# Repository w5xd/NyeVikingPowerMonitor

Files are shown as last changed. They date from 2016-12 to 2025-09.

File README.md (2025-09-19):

# Nye Viking RF Power Monitor
Brain transplant for Nye Viking Power Monitor RFM-003

My old RFM-003 quit working. I had purchased it new in 1988 and it has been my go-to device
ever since. It was produced by Nye Viking 
in Bellevue, Washington  through the 1980's and 1990's. Its original 
design is an analog computer that converts the two voltages (forward and reflected) from a directional coupler to present an SWR reading and 
an RF Power reading on analog meters. 

After switching out the obvious parts, I gave up trying to fix mine and
instead started prototyping with an Arduino single-board computer and its mating Proto Shield circuit board.
This git repo documents the hardware and software needed to replace the OEM analog computer with what I finally came up with: an
Arduino-based custom printed circuit board (PCB).  

Old Nye Viking power meters also become available from time to time "for parts only."
This project presents a four layer PCB design that has the same functions as the OEM PCB, supports the
same switches and connectors on the OEM device's front and back panels, and can be retrofitted into an OEM RFM-003 console
to restore all of its original functionality.

Don't know about the Nye Viking Power Monitor? Here is a demonstration videoed by N8RWS:<br/> http://www.youtube.com/watch?v=muCM9BKhpKA

When I did the retrofit of my own two Nye Viking consoles, I took the liberty of making three
exernally visible changes: I substituted 
RGB diodes on the front panel, drilled a small back panel hole for a USB port, and placed a small
momentary contact SPST switch in what was the back panel ALO sense adjustment hole. If you forego those three
substitutions, you can make it difficult to distinguish the OEM console from the retrofit&mdash;even in operation.  (Spoiler:
feed the retrofit less than 20W and it changes the front panel LED color and brightness while simultaneously
displaying the power meter readout multiplied by 10, which the OEM won't do.) 

# History
The original instrument has a single circuit board. Here is a photo with its cover removed.
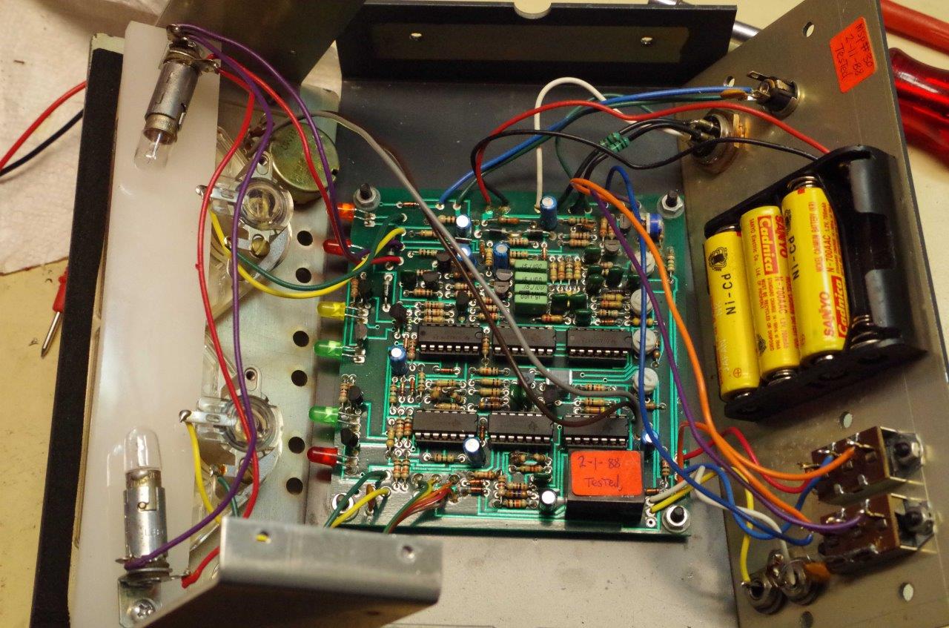
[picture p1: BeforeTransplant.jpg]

<p> This github repo documents 
a replacement project done in 2023 that is based on a custom printed circuit board documented
in the PCB folder. If you want the full history, the git tag 
<a href='https://github.com/w5xd/NyeVikingPowerMonitor/tree/Final-Haywire-Prototype'>Final-Haywire-Prototype</a> 
documents the first steps in this project back to 2016, and before the design of the custom
PCB. </p>

September, 2025

The latest revision updates the sketch, replaces
the console 3D printable work-alike, and updates the PCB design. 

<h2>Construction</h2>
The custom PCB is 2 inches by 4 inches. Its circuit diagram is <a href='PCB/schematics.pdf'>
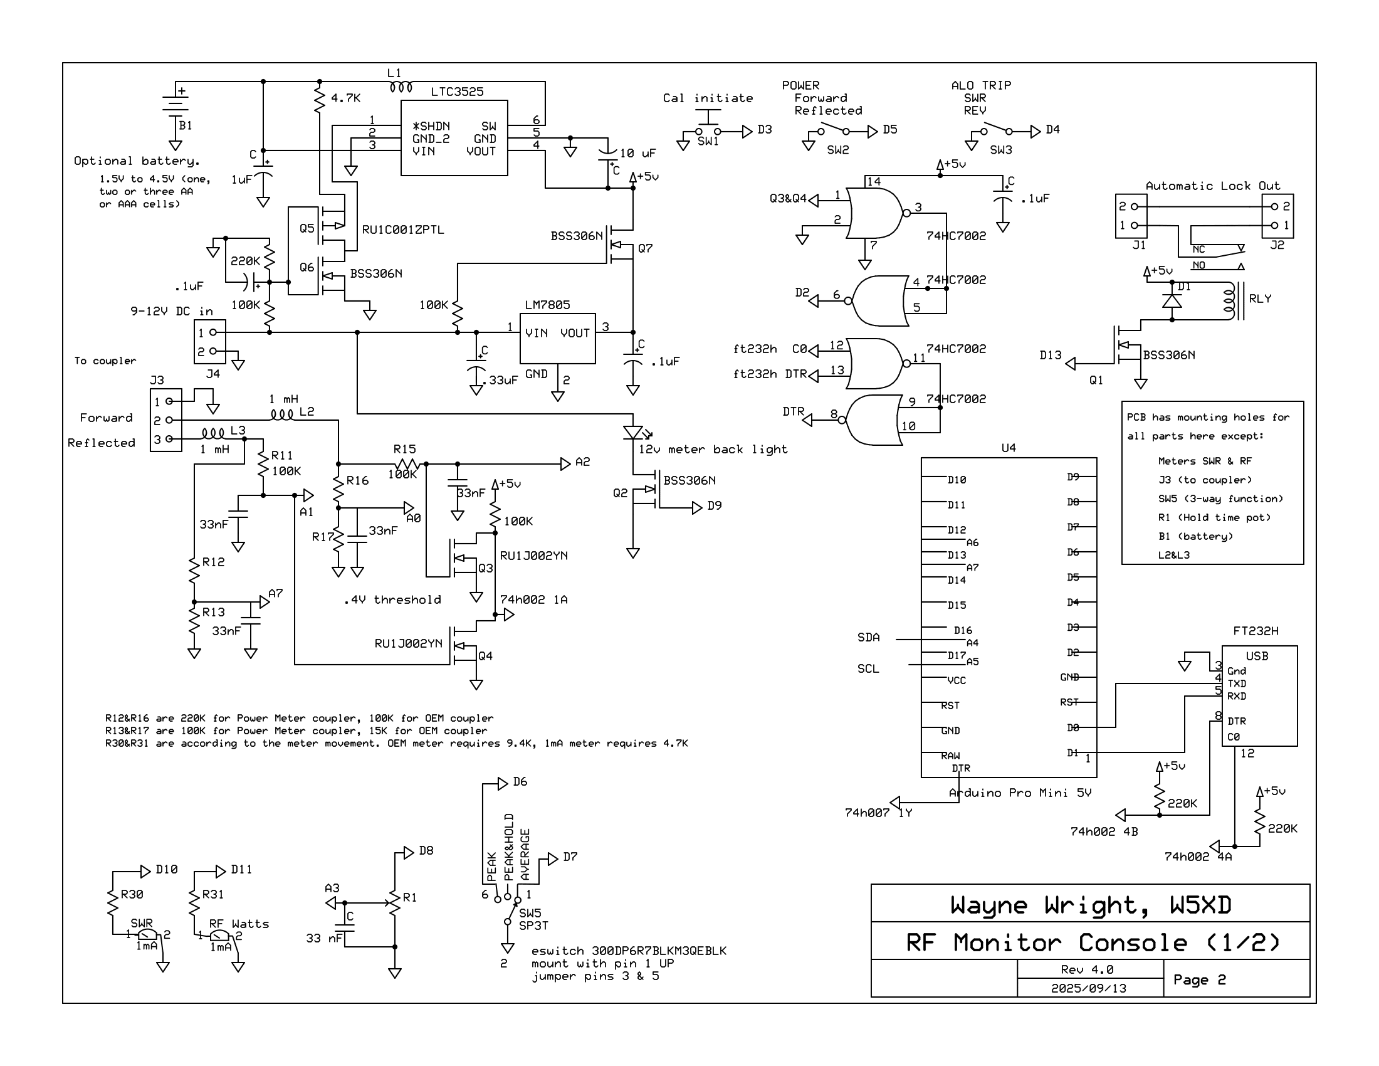
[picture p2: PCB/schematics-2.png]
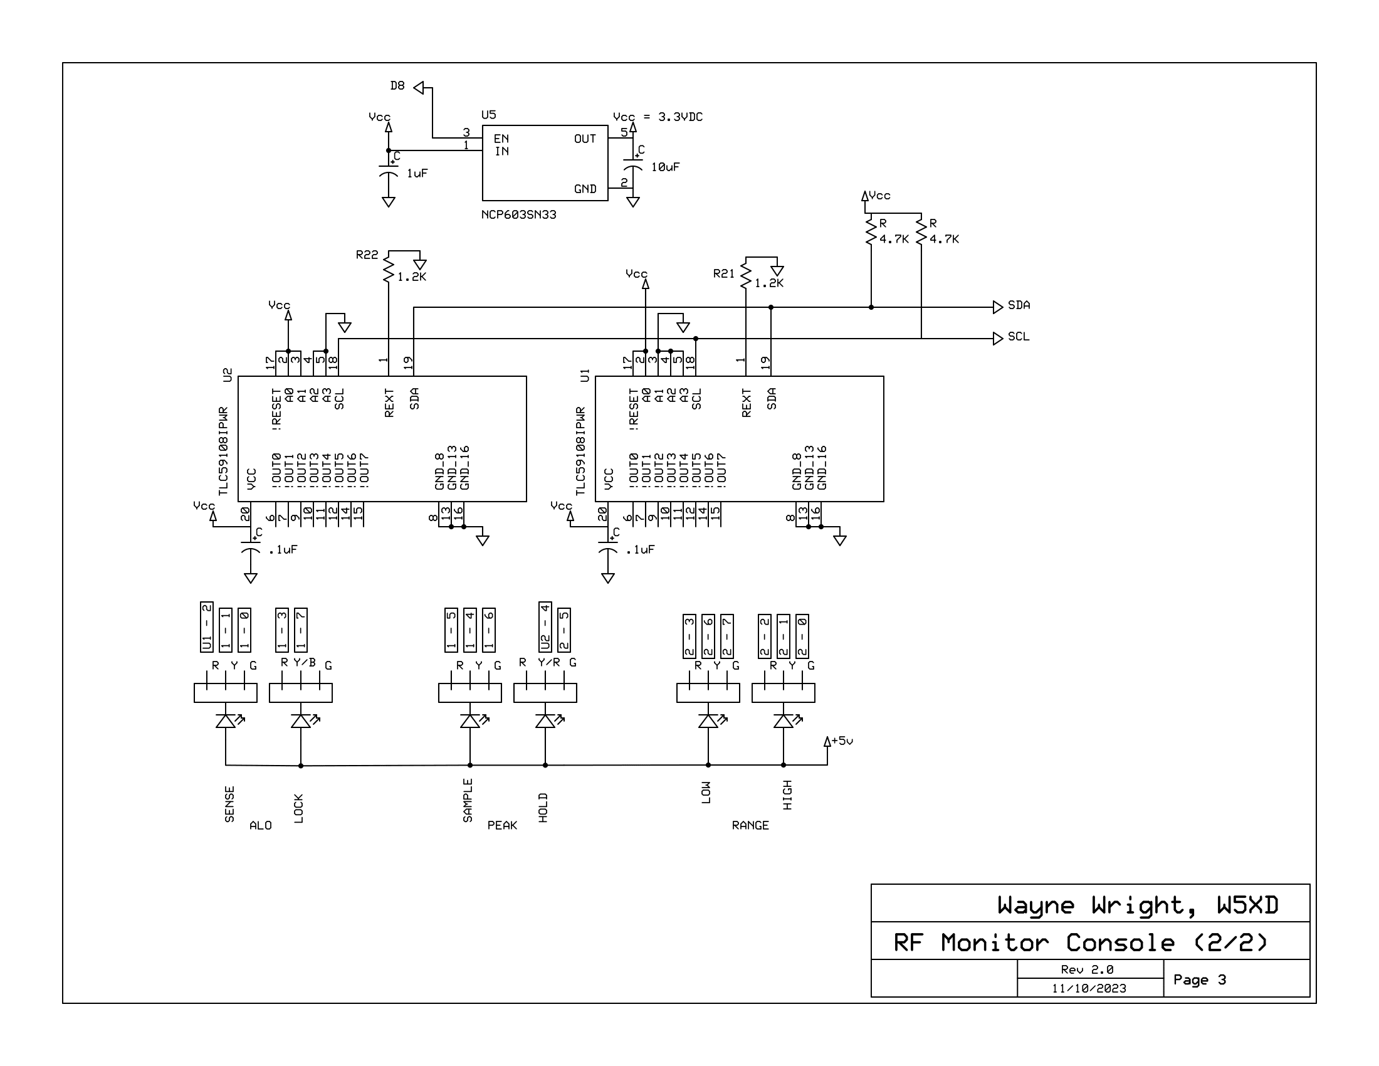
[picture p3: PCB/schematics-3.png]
page3
</a>The
PCB's construction sources are 
published here in the format supported by expresspcb.com, along with gerber files that
commercial PCB manufacturers can use to reproduce them. Parts lists
for duplicating this retrofit are linked below. Two additional projects are documented:
<ul>
<li>A work-alike console can be bult using the same retrofit PCB and it fits in the 3D printed enclosure documented below.
<li>The directional coupler documented below supports the range 1.8MHz to 29MHz and power between 5W to 3000W. 
The retrofit PCB will work with it, whether in an OEM console that maybe you acquired without its coupler, or with
the work-alike console. (The only combination that doesn't work is the 
unmodifed OEM console will <i>not</i> work with this coupler, even though the
connectors are compatible.)
</ul>

# OEM console disassembly
<p>The original box splits along its clam shell by first removing the top two screws from the right hand side,
the top two screws from the left hand side to remove the top. Then the outer-most four screws from the back panel.
To fold the front panel away, remove the bottom two screws <i>on the two side panels only</i>.
 Do not remove any
front panel screws nor the bottom panel screws.</p>
<p>I removed the original board by snipping each wire at its end at the original circuit board. 
Some of the resulting wires
will reach to their assigned position on the new PCB, but some will not. The custom PCB
fits onto a 3D printed bracket that has holes to match the original four #6 screws that held the OEM
PCB in place, and that has six by 5mm LED holes to match the front panel LEDs. The bracket holds the
custom PCB at an angle.</p>
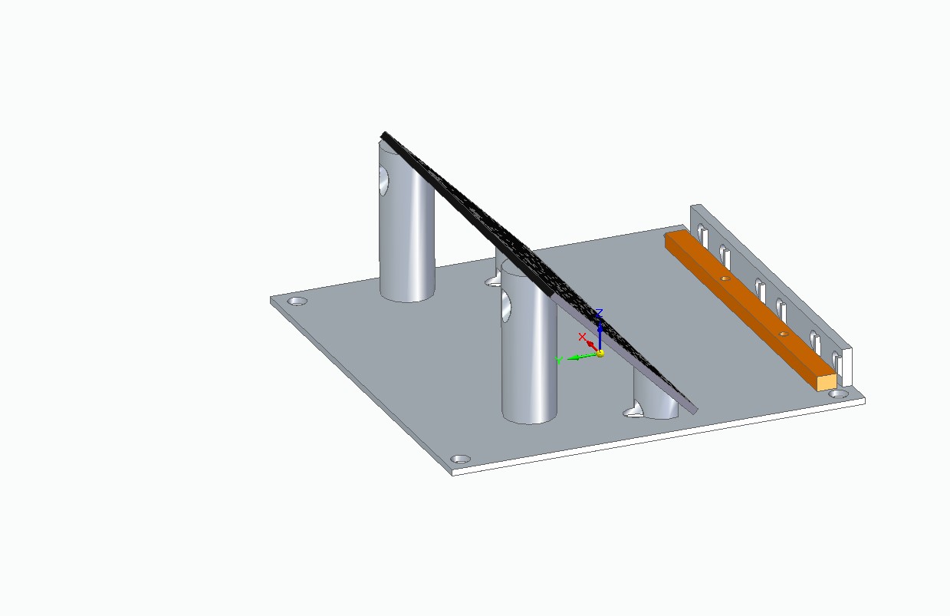
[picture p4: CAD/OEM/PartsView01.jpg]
OEM view

<p>A prospective builder will want to know that, while the 12VDC connector at the back
of the RFM-003 matches the voltage (about 12V), polarity (positive on the inner pin, 2.5mm) and
outer diameter, (5.5mm) that is standard on AVR-based Arduinos, the diameters of the inner pins do NOT match. The Arduino power plugs have
a 2.1mm inner pin. </p>

<a href='PCB/ConsolePcbMap.pdf'>Map of the console PCB</a>

<h2>Added low-low power feature</h2>
<p>While the code (nearly) duplicates the original behavior of the analog board, there is
 one additional low power readout feature. When it detects power levels below 1/10 of full scale in the LOW RANGE, it 
 multiplies the value on the meter by 10 (so 5 watts goes to 50 on the meter scale) and 
it changes the color of, and lowers the brightness of, the LOW LED.
</p>
<h2>SWR and RF Power</h2>
The DC voltages from the OEM coupler are input on a 4 pin jack. The pins are ground, foward signal, 
reflected signal, and battery charge. The retrofit PCB does not have a battery recharge circuit.
Therefore there is no connection on the battery charge
voltage on that fourth pin, but is built with a 4 pin connector that mates compatibly with OEM part.
 The forward and reflected signal voltages are processed into
 SWR and RF power readings that are presented on analog meters. The overall signal processing is
equivalent in this retrofit to the OEM design. 
The sketch supports a compile time option to construct lookup tables for analog meter movements, either 
<ol type='a'>
<li>the OEM meters with their original scales. This is for a retrofit.
<li>1 mA movement meters with the mA scale replaced using the printout from the MeterFaces application here.
Without OEM meters, constructing a workalike console requires modifying commercially available meter faces
as described below.
</ol>

<h2>Switches and Potentiometer</h2>
This retrofit takes all the same user inputs as the original:
<ul>
<li>Front panel potentiometer for Hold Time
<li>Front panel three-position switch for metering mode: Peak, Peak & Hold, Average
<li>Back panel ALO selection between SWR and Reverse Power
<li>Back panel Power selection between Forward and Reflected to drive the front panel Power meter
<li>Back panel ALO RCA jacks that break continuity on detecting a lock out condition.
</ul>
<p>The retrofit adds a momentary action pushbutton switch to the back panel that is not in the OEM design. Pressing 
the button places the meter 
in calibrate mode so that
you can adjust, within a restricted range, the meter's power sensitivity. This feature is in lieu of the
calibration pots on the OEM PCB. A commerically available
push button SPST switch fits in the OEM case in the original hole labeled ALO Adjust. That is, you
don't need to drill any new holes for a retrofit
</p>

<h2>Forward and Reflected signals</h2>
<p>
In this retrofit design, the Forward and Reflected readings from the coupler are treated identically 
to each other in the circuits leading up to
the analog to digital conversion. Each signal input is fed undivided into an ADC input on the Arduino through a 
100K resistor.
This signal path is used for best resolution at low RF power up until the digitized voltage exceeds
the 5V maximum supported by the Arduino ADC inputs. The 100K resistor
limits current under high power signals which can range up to about 15V for this coupler, or 26V for the
OEM 3000W coupler. The forward power signal is also voltage divided into a second ADC input channel, 
with the divider set to be enough to bring
the highest measureable power (3000W) down below the 5V maximum. The program in the sketch
tries the undivided voltage first, notes if it is maxed out and then tries again with the divided input. This
allocation of two ADC pins for each power input gives good low power resolution while still accommodating 
3000W without overflowing the ADC.
</p>

<h2>Console DC Power</h2>
<p>The DC power supply design here has one, but only one, important similarity to the OEM design: it can  
accept external DC input at (about) 12VDC, and seamlessly switchover to battery power when external DC is not present. 
The OEM design required four rechargable NiCad AA cells which served not only as the
battery power source, but also as the voltage regulator in its circuit that converts 12VDC input to 
regulated ~5VDC.</p>

This retrofit, by contrast, includes no recharging circuit, nor does it require any battery installed at all&mdash;they are optional.
The external DC jack accepts a range of input voltage from about 7VDC up to a maximum of 15V.
Its battery power circuit, based on the LTC3525, works with pretty
much any battery technology and voltage from about 1.0 VDC up to 5VDC. It can convert any battery voltage 
as low as 1V up to 5VDC, but, to repeat, there is no charger in this
design. On the other hand, it hardly needs a charger. Ninety seconds after last detecting RF power present, the 
Arduino sketch puts the CPU into
power down sleep mode, which consumes less than 10 micro Amps (uA). Even a very modest battery, a single AAA alkaline
 cell, will last for over 1000 hours of standby. The IC maintains a steady 5VDC power supply for the monitor as the battery
loses voltage until the battery can no longer maintain about 1V at the LTC3525, at which point the IC shuts down.
There is no power on/off switch. It doesn't need one.

The maximum number of AA or AAA cells in a battery for the LTC8525 part is <b>three</b>.
This limit is necessary in order to stay below
its 6VDC absolute maximum battery voltage input for the LTC8525. The OEM meter from Nye Viking
houses <b>four</b> AA NiCads. That battery holder can be retained in this retrofit,
but it can only be used if one of the cells is replaced with a
dummy AA cell. The original NiCads can be used (if they still work after all these years! but, again, 
only <i>three</i> of them) and 
they'll have to be recharged outside the meter.

The seamless battery power switchover is implemented by Q5, Q6, and Q7. The first two are 
complimentary MOSFETs, P-channel
and N-channel, respectively, in a push-pull arrangement with their gates driven from the back panel DC input jack voltage.
Their drain pins control the
DC-to-DC converter's shutdown input. When that back panel jack is not
powered, the gates are at ground voltage, which turns on the P channel, Q5, (its source pin 
as at the battery 
voltage, which, of course, must be present to run the device on battery power) while the 
N channel, Q6, is off. 
That is the battery power state of the solid state switch. Apply power to the back panel 
jack (which will get Q6's gate above its threshold turn-on voltage) and it
turns on the N-channel while turning the P-channel off. The drains of both Q5 & Q6 drive the SHDN input 
of the DC-to-DC converter, 
which turns it on in the former case of battery
power, or off for external DC power. The 4.7K resistor limits the drain currents in the case 
(which should never happen) of both Q5 and Q6 turning on simultaneously.

The Q7 "ideal diode" implementation
connects the LM7805 output
 only when DC power is present on the back panel, because an inactive LM7805 draws about 30mA
 when 5VDC is connected to its output. External
DC input pulls Q7's gate more than its gate threshold above the 5V regulated power (i.e. 
~7V input turns Q7 on as
its gate threshold specification is about 2V.) The LTC3525 does not need a disconnect as its SHDN 
input accomplishes that function.

Acheiving the less-than-10uA standby current is dependent on the details of how the FT232H 
serial breakout is
set up as detailed in the following section. Also, the SJ1 solder jumper on the Arduino Pro Mini
must be separated.

<p>To populate a PCB without battery power support, the following part positions on the PCB may
be left empty: LTC3525, L1, Q5, Q6, Q7, NPC603.
With those parts omitted, there are two jumper positions labeled on the board that must be 
jumpered: jp1 (near the NPC603) and jp2
(near Q7).
</p>

<h2>USB interface</h2>
<p>
This design has a USB interface using the FT232H that presents on a PC as a COM port. The sketch supports
some simple Serial port commands that can be used to remotely monitor forward and reverse voltages. A USB
 jack can be installed on the back of the OEM console (if you are willing to violate a "no holes" requirement
 for your vintage enclosure.) A USB-C port will fit in a small hole drilled in the back panel's
upper right corner, just above the 12VDC external power jack, should you choose to drill.
</p>
<p> The sketch can be
uploaded onto the Arduino using USB. (or the ISP pads on the PCB can alternatively be used to program the Arduino.) 
 The FT232H on the Adafruit breakout board has an EEPROM that can
be configured using <a href='https://ftdichip.com/utilities/#ft_prog'>FTDI's FT_Prog.exe</a>, also over
 that same USB port. 
To program the Arduino, use the FT_Prog application to set the FT232H C0 output to Drive_0. The Drive_0 setting
 enables the
Arduino IDE to invoke a reset on the PCB using serial port DTR per the usual convention for Arduino FTDI headers.
The FTDI programming screen looks like this:
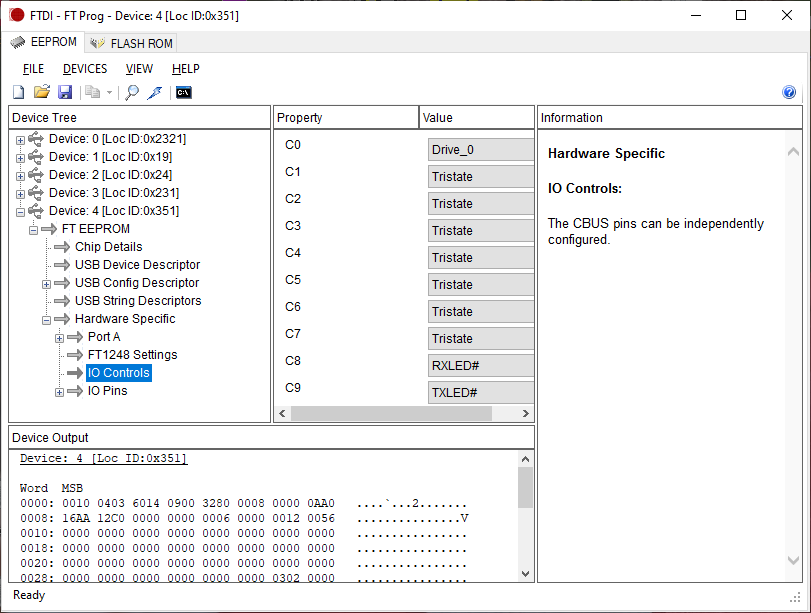
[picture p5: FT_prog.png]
FT_Prog

The setup as shown makes it easy to upload sketches. Be aware, however, that the <code>C0 at Drive_0</code> 
setting draws about 200 uA 
continuously as long as the FT232H is connected to a powered USB port.
 If the PCB has USB power without back panel 12V DC, this will draw down the battery much more quickly.
Use FT_Prog to set C0 to Tristate to reduce the drain, but that setting makes it 
more difficult to program the Arduino
through the serial port because you have to accurate time pressing the Arduino's reset button.
(Why program the C0 output? It is an EEPROM setting that enables or disables the reboot of the Arduino when
a Windows app opens the COMM port which, in turn, asserts DTR. For uploading sketches, you want the reboot, but the
reboot is a problem if you are using the NyeVikingMonitor Windows app published here.)
The C8 and C9 outputs driving TXLED and RXLED shown in the screen above are for 
convenience. They make it easy to see that the 
Arduino program upload is proceeding as expected.</p>

Another ~200uA is consumed, regardless of the FT232H EEPROM settings if the DTR on 
the FT232H's serial port is
not asserted. This 200 uA can also be eliminated either of these ways:
<ol type='a'>
<li>Unplug the FT232H from the circuit such that there is no USB at all.
<li>Power the FT232H's USB only while 12VDC is presented on the back panel. That is, if 
the unit is on battery power, the FT232H will draw pull up current from that battery
while a USB connector is plugged in.
</ol>

<h2>Front Panel LEDs</h2>
<p>This PCB design employs a pair of general purpose TLC59108 LED driver chips that together can drive 
up to 16 diodes on a common annode circuit. The PCB routes those 16 outputs to 6 physical positions 
corresponding to
the OEM console's front panel LEDs (labeled, left to right, SENSE, LOCK, SAMPLE, HOLD, LOW and 
HIGH.) To easily retrofit into the OEM case, use size T1-3/4 diodes (5mm diameter.) Instead of the OEM's 
specific color 
diode at each of the six positions, I chose six identical RGB diodes (part number listed below)
 and programmed the sketch to synthesize 
the yellow and amber from
the 3 colors available.
The sketch includes compile time conditionals for supporting either six of RGB or six of RGY diodes. 
Modify the sketch to use whatever 
color scheme you want.

Of the six front panel LED positions, the LOCK and the HOLD positions only support 2 of the LED
colors because the IC's 16 channels can cover all of 3 channels on each of 6 posiitions.
The sketch simulates an amber color using a combination of two parts red with one part green, and 
simulates yellow with
equal parts red and green.
Alternatively, you can scavange the six OEM LEDS
when you retrofit, and you can make this PCB successfully drive them, but you'll need to modify the
sketch accordingly. 

<h2 id='Couplers'>Couplers</h2>
The PCB and sketch support two different coupler implementations.
<ol><li>The OEM 3000W coupler</li>
<li>This build-it-yourself <a href='./coupler'>coupler</a> based on the design in the 2008 Radio 
Amateur's Handbook.</li></ol>
 <p>This <a href='./coupler'>coupler's</a> detection sensistivity does not match
the OEM coupler, and therefore requires different resistors in the voltage dividers feeding the Arduino ADC's, and 
some different coefficients in the sketch's ino file.
It is enclosed in a commerically available clam shell aluminum box.
The primary advantage of this particular coupler design from the Handbook is that its balance depends only on
your ability to wind two identical transformers (i.e. you have to be able to accurately count to 40),
and use well matched resistors and diodes. There are 
no balance or level
adjustments.
This one has a more inductive toroid transformer design than the
Handbook design (a stacked trio of T80-2 toroids instead of the 
single T68-2 in the Handbook)
which improves 1.8MHz performance.
The 40:1 turns
ratio (which was the Handbook design, which this unit matches) gives somewhat smaller DC voltages at its 
detectors than the OEM 
Nye Viking design. Decreasing the turns ratio would
increase the voltage transfer, but that reduction also reduces the transformer's inductive reactance. 
The trio of T80-2's is already just
barely inductive enough to be used at 1.8MHz (and I don't think the 2008 Handbook design 
worked very well at 1.8MHz.)
The coupler as described displays the equivalent of about 7 ohms of inductive
reactance in series with a pure 50 ohm load at 1.8MHz which shows up as about a 1.15:1 SWR looking into the coupler from 
the transmitter at that frequency, even though the coupler reads out 1:1. The reactance of the coupler
measured as insignificant on all the remaining HF amateur bands 3.5MHz through 29MHz. This coupler
does not work acceptably above 30MHz.

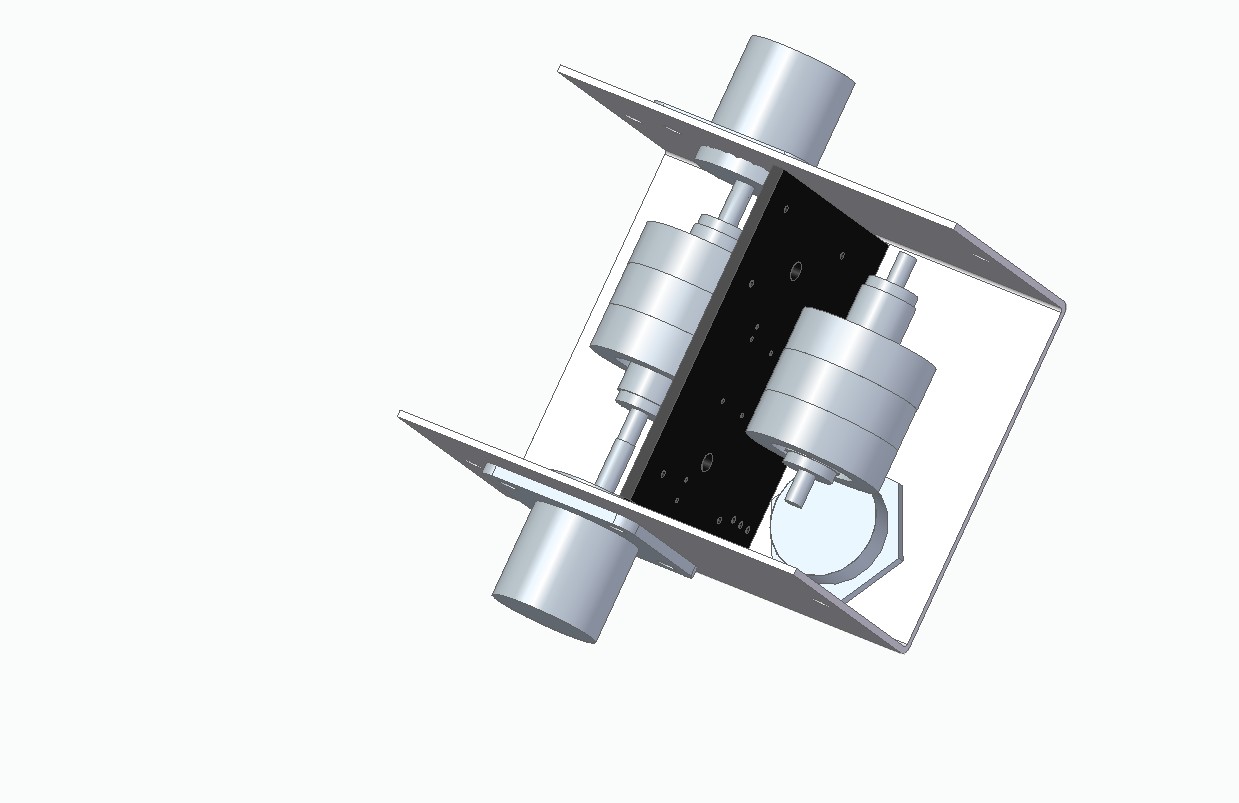
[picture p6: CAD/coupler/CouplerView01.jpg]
OEM view

<p>Details are in the <a href='./coupler'>coupler</a> folder.</p>

<h2>Build a Console from Scratch</h2>
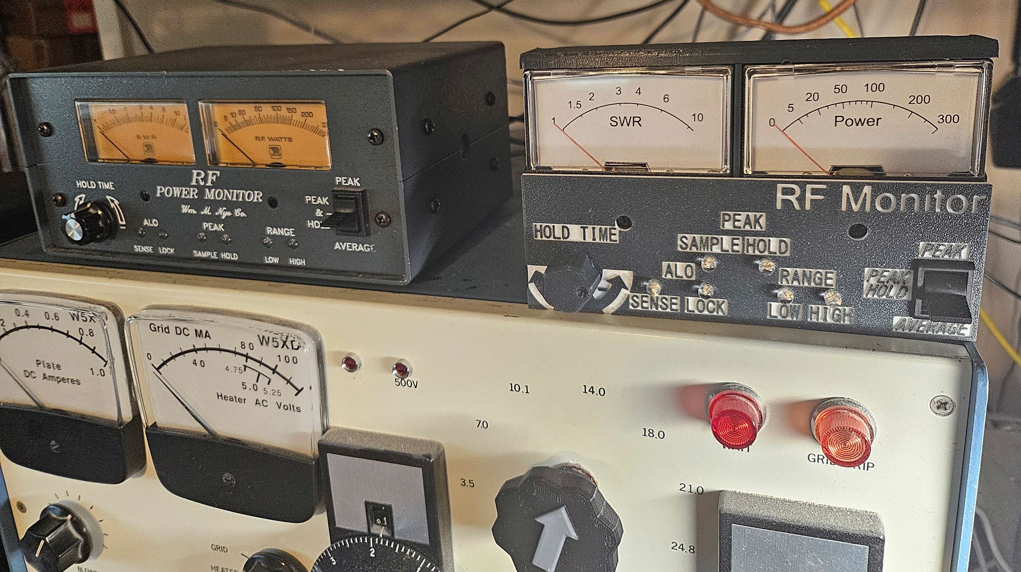
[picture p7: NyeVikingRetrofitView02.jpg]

<p>If you don't have an existing OEM unit to retrofit an entire workalike unit can be built using the 
design in this repository. The photo shows a retrofitted OEM unit on the left, and, on the
right, a complete workalike in a 3D printed enclosure build around the same PCB. (This 
is not the only Nye Viking RFM-3000 workalike that has been designed. 
See the <a href='https://www.eham.net/reviews/view-product?id=4907'>RadioCraft 3000 Pro</a>.)
</p>
<p>
You'll need both a coupler and a console. Resistor value choices in this workalike console
support either the voltage levels presented by the OEM coupler, or those from the couple documented
above. </p>
<p>A 3D printed enclosure design is documented here that
supports the 
<a href='https://baomain.com/products/baomain-dh-670-1-ma'>Baomain Ammeter DH-670 DC 0-1.0 mA meter</a>. 
And listed on
<a href='https://www.amazon.com/dp/B01HPKO8CS'>Amazon</a>
The meter faces can be replaced using those drawn by the MeterFaces program <a href='MeterFaces'>here</a>.
<table style='width:100%'><tr><td style="width:50%">
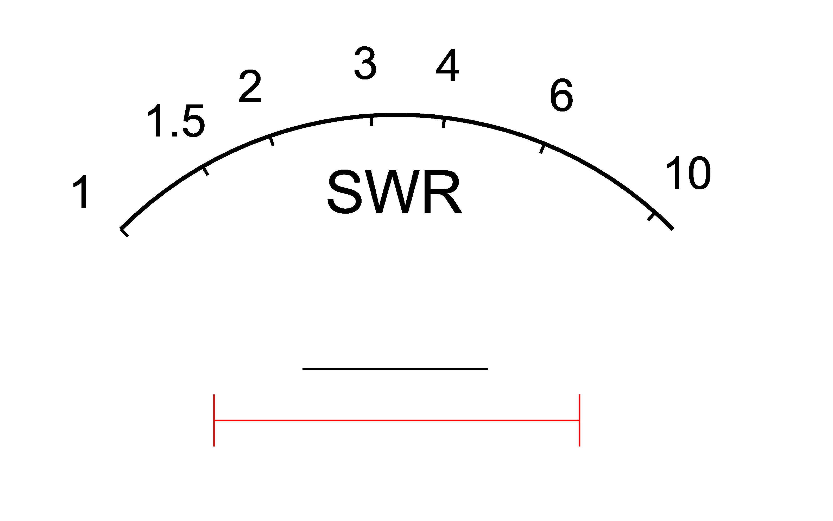
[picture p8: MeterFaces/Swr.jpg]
swr
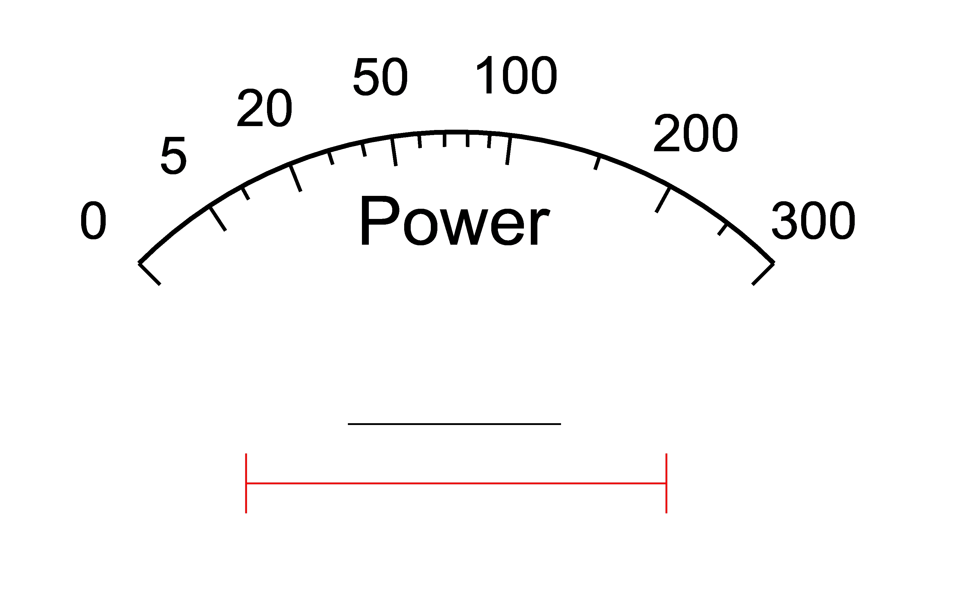
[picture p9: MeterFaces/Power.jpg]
power
</td><td>
</td></tr></table>
I tried several different LED parts for the workalike. Eventually, I gave up trying to successfully mount SMT
LEDs on the PCB. The hole pattern on the PCB supports 4 pin RGB T1-3/4 LED lamps, which are 5mm diameter. 
2 pin single color LEDs work too.
2mm end glow fiber optic cable
transfers the light to the front panel.

The 4 layer PCB provides adequate shielding for my own shack, even with full legal limit power
output to a tribander directly above the operating position.

The 3D printable files for the console are in the
<a href='STL/console'>STL/console</a> folder.

 <h2>Calibration</h2>
 <p>The sketch supports four calibrations in EEPROM accessible using the back panel
calibrate push button. These four roughly correspond to 
 potentiometers on the original analog board. The EEPROM settings are:
 <br/>ALO SWR lock-out threshold
 <br/>ALO PWR lock-out threshold
 <br/>Foward voltage calibration correction (restricted to a +/-5%) range
 <br/>Reflected voltage calibration correction (also restricted to a +/-5%) range
 </p><p>
 Setting the EEPROM values is accomplished using the back panel pushbutton switch
 followed by turning the front panel HOLD pot. See the code for full instructions.
 </p>
The sketch has additional settings accessible only through its serial port interface. See
the <a href='PowerMeter/PowerMeter.ino'>ino file</a> for details.
 
<h2>Parts Lists</h2>
<ul>
<li>These parts are needed on the PCB regardless of whether you are doing a retrofit or a complete console. 
<a href='https://www.digikey.com/short/wrb8bqwj'>https://www.digikey.com/short/wrb8bqwj</a>.
And the PCB in <code>PCB/Power console.rrb</code> which can be ordered from expresspcb.com using this rrb file.
<li>If you are doing a retrofit, you'll need the small push button that fits the ALO hole, and you likely want LED versions of the
lamp backlights: <a href='http://www.digikey.com/short/5m7ddj84'>http://www.digikey.com/short/5m7ddj84</a>. You'll need
to 3D print the bracket here <code>CAD/OEM/Retrofit-board.stp</code>, and the LED holder here <code>CAD/OEM/LED backstop.stp</code>.
Two machines screws, #2 x 7/16" with nuts hold the LED holder to the bracket.
<li>The mating DC power connector for the OEM console is the 
<a href='https://www.digikey.com/en/products/detail/cui-devices/PP3-002B/992137'>CUI Device 3-002B</a>.</li>
<li>Quantity 6 of the 5mm T 1-3/4 RGB LED 
<a href='https://www.digikey.com/en/products/detail/kingbright/WP154A4SEJ3VBDZGW-CA/6569334'>
https://www.digikey.com/en/products/detail/kingbright/WP154A4SEJ3VBDZGW-CA/6569334</a>. These
LEDs are needed if you either retrofit an OEM console and want to use RGB LEDs, or if you build a 
stand alone work-alike
console. Other RGB LED parts can be substituted, but look carefully at the pinout as supported
by this PCB and sketch. Not all T1-3/4 RGB LEDs have the same pinout. The supported pinout is four pins
with RABG in that order.</li>
<li>To build a stand alone console, you need to populate all the connectors on the PCB and the 
4 pin connector to the coupler.
<a href='https://www.digikey.com/short/w12hfd9z'>https://www.digikey.com/short/w12hfd9z</a>. 
Two panel meters are required as mentioned above.
<li>To build a coupler, you'll need these: <a href='http://www.digikey.com/short/9nb54202'>http://www.digikey.com/short/9nb54202</a>. 
And you'll need
quantity six <a href='https://www.amidoncorp.com/t80-2/'>T80-2 (red) toroids</a>, a few inches of RG-213,
and the custom <code>PCB/Power Coupler.rrb</code>.
</ul>

<h2>Construction Notes</h2>
<p>The console PCB in particular sports SMT devices with lead spacing way too small (0.65 mm) for me to 
hand solder. I use an SMD oven. Such ovens can be
purchased online, but I built one using a toaster oven and 
this <a href='https://whizoo.com/pages/buildguide'>kit</a>. 
</p>
<p>While it is possible to generate and 3D print a solder paste mask starting 
from the gerber files you will get if you buy a PCB from expresspcb, I
did the solder paste spreading by hand. For
parts with leads this small, I have had better luck spreading the solder paste using a piece of 
bare wire, #20 or #22, as a tool.
I squeeze out a small amount of solder paste on a piece of scrap paper and dab it onto all the pads on the PCB. It will take
some practice to know how much paste is enough, but here is a rule: too much paste is far harder to repair later than too little.
And it is surprising how little will work. It is not necessary for the space between the pads to be completely clear
of paste, but don't leave any big blobs. I found that if I could get the paste to form a thing string
from my wire tool, that one strand of that thin string laid down across the entire row of 10 pins from pins 1 through 10
 of the LED driver baked well. If a solder bridge forms while baking, I found that a fresh
piece of copper de-soldering braid would usually remove the bridge first try. </p>
<p>
The SMD ICs put up with some abuse from my mistakes. I had placed the 6 pin 5V step-up IC rotated 180 
degrees from its proper position. 
When the board wouldn't do battery power and I diagnosed my error, I was able to use a hot air SMD tool to 
remove it, rotate it, and I put the
same one back in. (Each costs over $5 and I wanted to at least try.) It worked. I was also able to remove 
the 20 pin LED driver ICs
from an early prototype board and mount them on an updated PCB successfully.
</p>
<p>
You can use the Arduino IDE to program the sketch onto the Sparkfun Pro Mini board 
(be sure to get the 5V version of the Pro Mini!) 
Its recommended you first program the LedTest sketch here and type its 
various commands after you get the LEDs connected, but
before you install the PCB in the console. 
</p>
<p>
Program the PowerMeter.ino sketch when you are happy the board is OK. 
Do <i>not</i> change that sketch's disable of the
watchdog timer <code>#define</code>
unless you are willing to learn how to program the Arduino using the 6 pin ISP pads 
on the PCB. The default bootloader in
the Pro Mini completely fails on the hardware watchdog timer reset. Have a look at
boards-to-add.txt for hints on how to update the Arduino IDE install to support the WDT. 
Do you need the WDT? My prototyped
version of this sketch on an Arduino PRO I left unmodified for 5 years without thinking I 
might want the watchdog. I
saw one hang during the testing of a prototype of this custom PCB version. Then I decided 
to throw in WDT (watchdog timer) support. At that 
point I discovered 
it was not as simple as
I wanted, but if you have an ISP programmer and figure out how to use it, its manageable.
</p>
<h2 id='RFM005'>What about the RFM-005?</h2>
<p>I don't have one to test with, but it should work with some modest 
modifications. Based on the comment in the OEM manual that all the Nye Viking
"directional couplers are calibrated for complete interchangeability" I deduce
that the resistor values as labeled on this PCB for the OEM coupler 
will work for any Nye Viking coupler under the assumption that "complete interchangeability"
 implies no internal adjustments are needed.</p>
<p>The RFM-005's front panel power meter, however, will require modifying
at least the <code>PwmToPwr</code> lookup table in the sketch. If 
the meter movement in the RFM-005 happens to be 0.5mA full scale
like both the power meter and SWR meter movements in the RFM-003,
then the OEM PCB values labeled here should work for both the
RFM-003 and RFM-005.</p>

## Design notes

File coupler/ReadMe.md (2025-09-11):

# Coupler Details
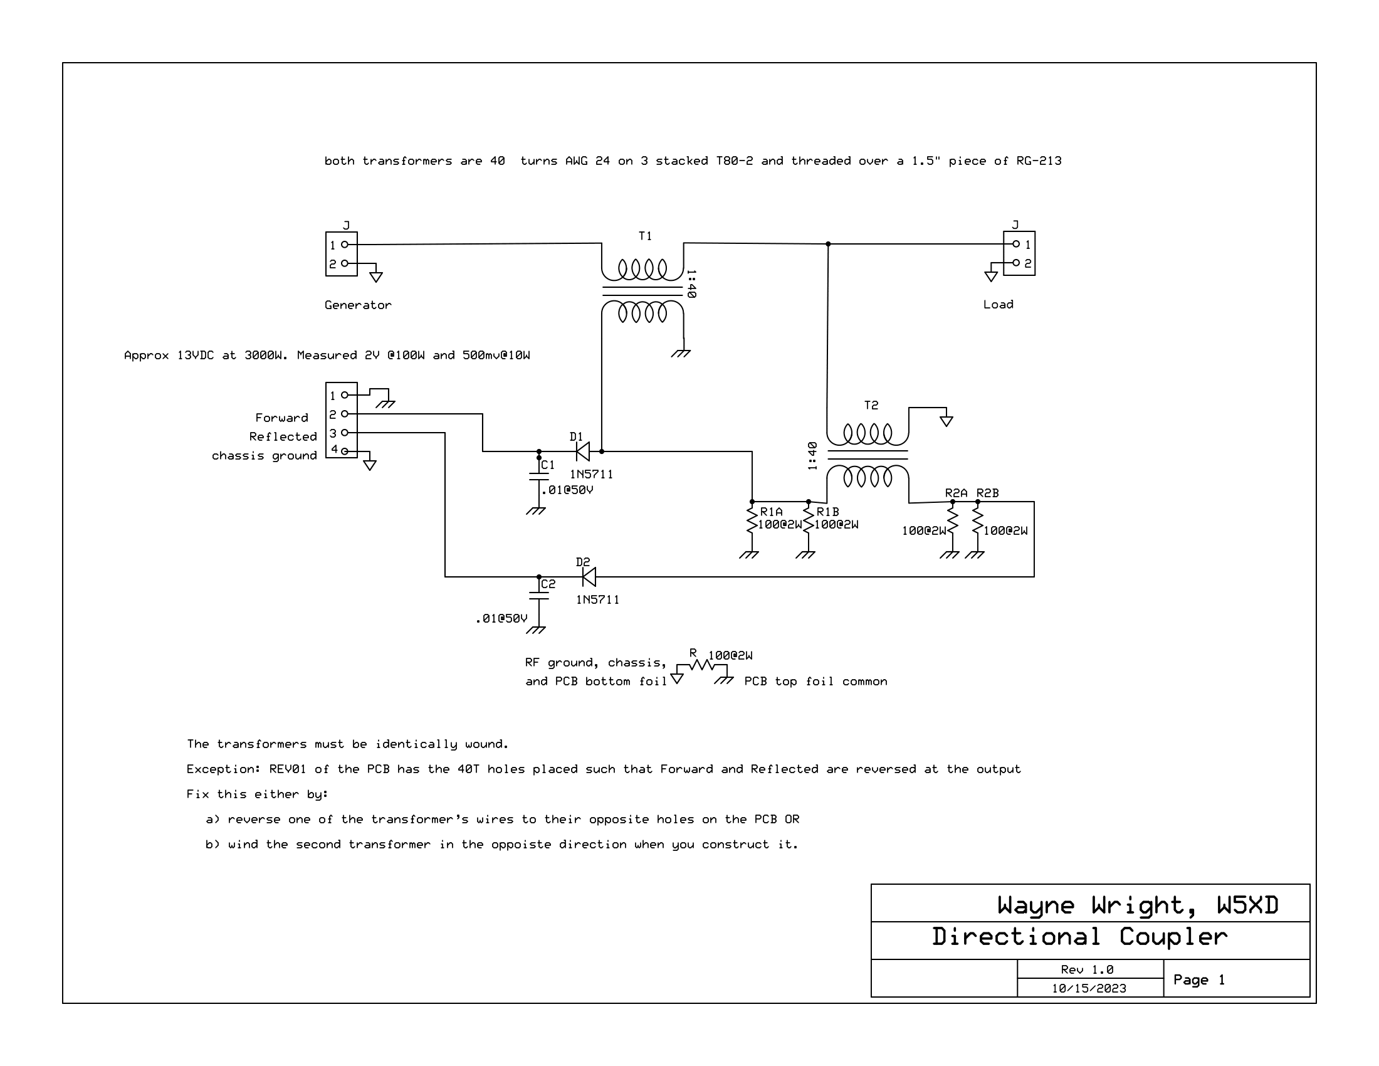
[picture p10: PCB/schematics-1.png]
page1
A build-it-yourself coupler schematic is here: 
The two layer PCB documented in the PCB folder makes it easy to construct.
The hole pattern for the 1411B aluminum box sides are:
<ul>
<li><a href='Front-template.pdf'>Front-template.pdf</a>
<li><a href='back-template.pdf'>back-template.pdf</a>
<li><a href='bottom-template.pdf'>bottom-template.pdf</a>
</ul>
<a href='../PCB/CouplerPcbMap.pdf'>Map of the coupler PCB</a>
<p>A 0.63 inch (or 16mm) metal punch is recommended for the SO-239 holes, as well as the 4-pin connector hole </p>
<p>The T1 side of the coupler:</p>
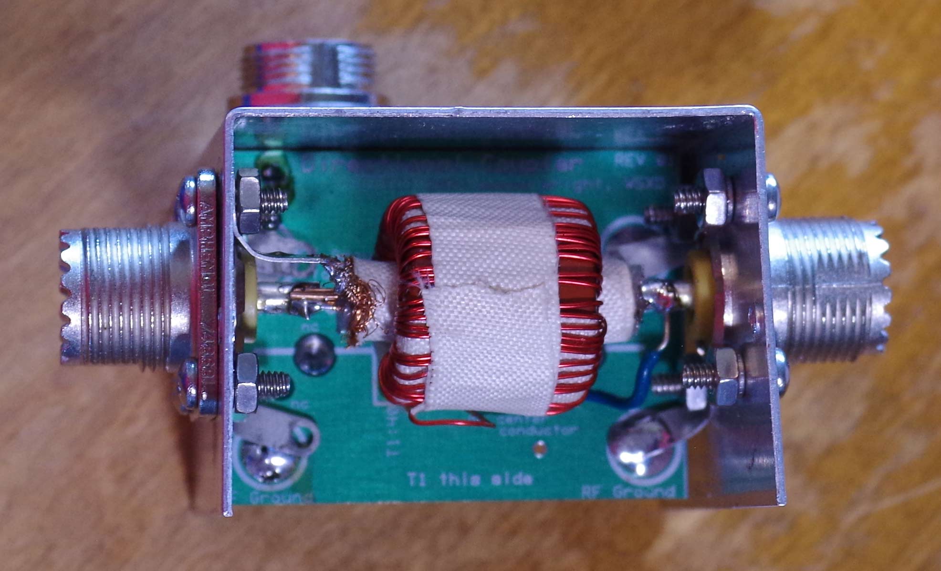
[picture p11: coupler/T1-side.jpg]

<p>The T2 side of the coupler:</p>
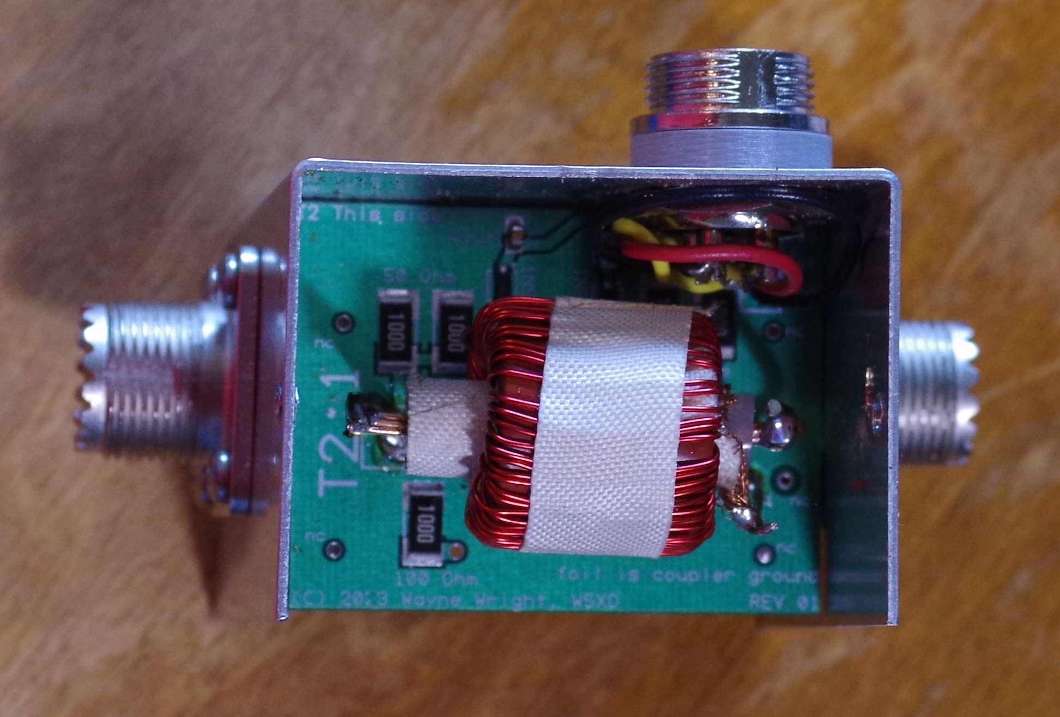
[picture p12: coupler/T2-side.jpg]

The PCB holes for the 40-turn sides of T1 and T2 are such that routing their wires to the
closest holes reverses the Forward and Reflected voltages at the output. Get the right voltages
as marked Forward and Reflected by either
<ul>
<li>winding the two transformers with opposite pitch of each other
<li>...or...
<li>routing the 40-turn side of ONE of T1 or T2 to their more distant holes on the PCB
</ul>
<p>The tape holding the coil windings in place is fiberglass. There is another layer
of white tape holding the RG-213 braid in place.</p>
<p>One end <i>only</i> of the RG-213 braids is grounded.</p>
<p>T2 is held in place mechanically by the leads to its 1-turn winding. Those leads should be 14 gauge.</p>
<p>There is limited clearance inside the aluminum box. The <code>CliffCon-Spacer.stp</code> is a
3D printed spacer that makes more room inside the box to route the wires.</p>
<h2>Theory of Operation</h2>
<p>The easiest model to understand is to model T1 as an ideal current
transformer, and T2 as an ideal voltage transformer. That makes them
a current dependent current source, and a voltage dependent voltage
source, respectively. The
result looks like this:</p>
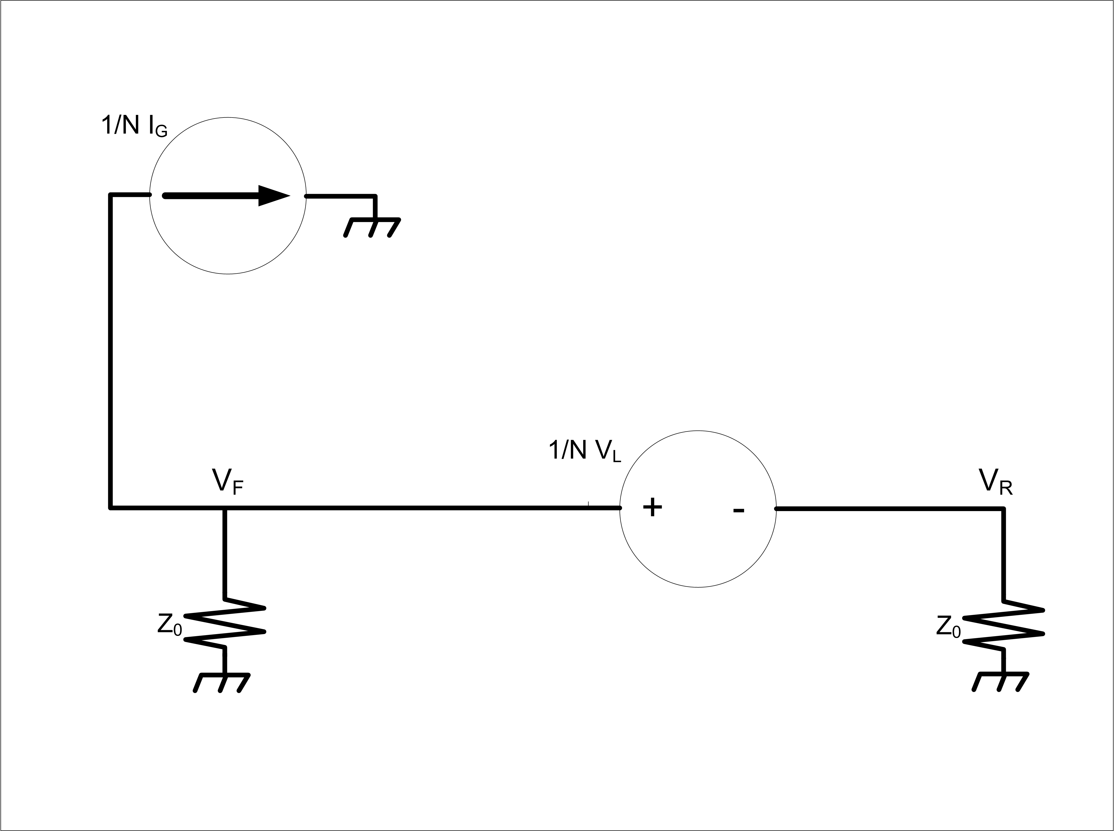
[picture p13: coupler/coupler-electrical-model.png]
coupler-electrical-model

<p>Z<sub>0</sub> is 50 ohms resistive in this design. I<sub>G</sub> is the current
into the generator, and V<sub>L</sub> is the voltage across the Load.</p>
<p>The polarity of the two transformers drawn in the PCB circuit board above
is would have this T1 current arrow in the opposite direction, but
the note says to reverse the polarity of either T1 or T2, so we'll chose
to reverse T1 for this model.</p>
<p>Inspecting the model, the voltage equation and the current equation are:
<br/>&nbsp;&nbsp;V<sub>F</sub> = V<sub>L</sub>&nbsp;/&nbsp;N + V<sub>R</sub>
<br/>&nbsp;&nbsp;-I<sub>G</sub>&nbsp;/&nbsp;N&nbsp;=&nbsp;V<sub>F</sub>&nbsp;/&nbsp;Z<sub>0</sub>+&nbsp;V<sub>R</sub>&nbsp;/&nbsp;Z<sub>0</sub>
</p>
<p>Solve for the two dependent voltages:
<br/>&nbsp;&nbsp;V<sub>F</sub>&nbsp;=&nbsp;1/&nbsp;2N&nbsp;(V<sub>L</sub>&nbsp;+&nbsp;I<sub>G</sub>&nbsp;Z<sub>0</sub>)
<br/>&nbsp;&nbsp;V<sub>R</sub>&nbsp;=&nbsp;1/&nbsp;2N&nbsp;(V<sub>L</sub>&nbsp;-&nbsp;I<sub>G</sub>&nbsp;Z<sub>0</sub>)
</p>

<p>Because the SWR is calculated from the detected values of the two voltages, its not possible
to ignore the time domain any further. The SWR equation, in prose, is "the sum of the detected voltages
divided by their difference." In the console, the SWR computation is:
<br/>SWR = ( | V<sub>F</sub> | + | V<sub>R</sub> | ) &divide; ( | V<sub>F</sub> | - | V<sub>R</sub> | )
</p>

<p>To sanity check this behavior, consider 
if I<sub>G</sub> happens to be matched and thus equal to  V<sub>L</sub>&nbsp;/&nbsp;Z<sub>0</sub> , then
we can see that the forward voltage is 1/N of the load voltage
and the reflected voltage is zero, and the SWR equation results in 1:1. This analysis is not frequency nor time dependent,
but its easy to see that to achieve zero V<sub>R</sub> at the diode detector,
that I<sub>G</sub> must not only have the matching amplitude, but also must
 be in phase with V<sub>L</sub>. That is to say, the
only way to get zero detected reflected voltage is for the load to be Z<sub>0</sub> resistive.</p>
<p>The short and open infinite SWR cases are also correctly covered. If the load is shorted, then V<sub>L</sub> is zero, or
if the load is open, then I<sub>G</sub> is zero. In both of those cases, the other term is non-zero which results in V<sub>F</sub> and V<sub>R</sub> 
having equal magnitudes to each other. When their amplitudes match, the SWR division blows up, which
is correct. (Their phases might not match each other, but the diode detectors
don't detect phase differences between V<sub>F</sub> and V<sub>R</sub>, while they are sensitive to
phase differences between V<sub>L</sub> and I<sub>G</sub>.)</p>
<p>To look at the more general case of arbitrary and possibly reactive load impedance, assume that T2's primary current is 
 neglible, and introduce the load impedance as Z<sub>L</sub> , we can substitute:
<br/>V<sub>L</sub>&nbsp;/&nbsp;Z<sub>L</sub> =&nbsp;I<sub>G</sub></p>
<p>Rearrange:
<br/>&nbsp;&nbsp;V<sub>F</sub>&nbsp;=&nbsp;V<sub>L</sub>&nbsp;/&nbsp;2N&nbsp;(1&nbsp;+&nbsp;Z<sub>0</sub>/Z<sub>L</sub>)
<br/>&nbsp;&nbsp;V<sub>R</sub>&nbsp;=&nbsp;V<sub>L</sub>&nbsp;/&nbsp;2N&nbsp;(1&nbsp;-&nbsp;Z<sub>0</sub>/Z<sub>L</sub>)
</p><p>Substitute for Z<sub>L</sub> :
<br/>SWR = ( |&nbsp1&nbsp;+&nbsp;Z<sub>0</sub>/Z<sub>L</sub>&nbsp| + |&nbsp1&nbsp;-&nbsp;Z<sub>0</sub>/Z<sub>L</sub>&nbsp| ) &divide; ( |&nbsp1&nbsp;+&nbsp;Z<sub>0</sub>/Z<sub>L</sub>&nbsp| - |&nbsp1&nbsp;-&nbsp;Z<sub>0</sub>/Z<sub>L</sub>&nbsp| )
</p>
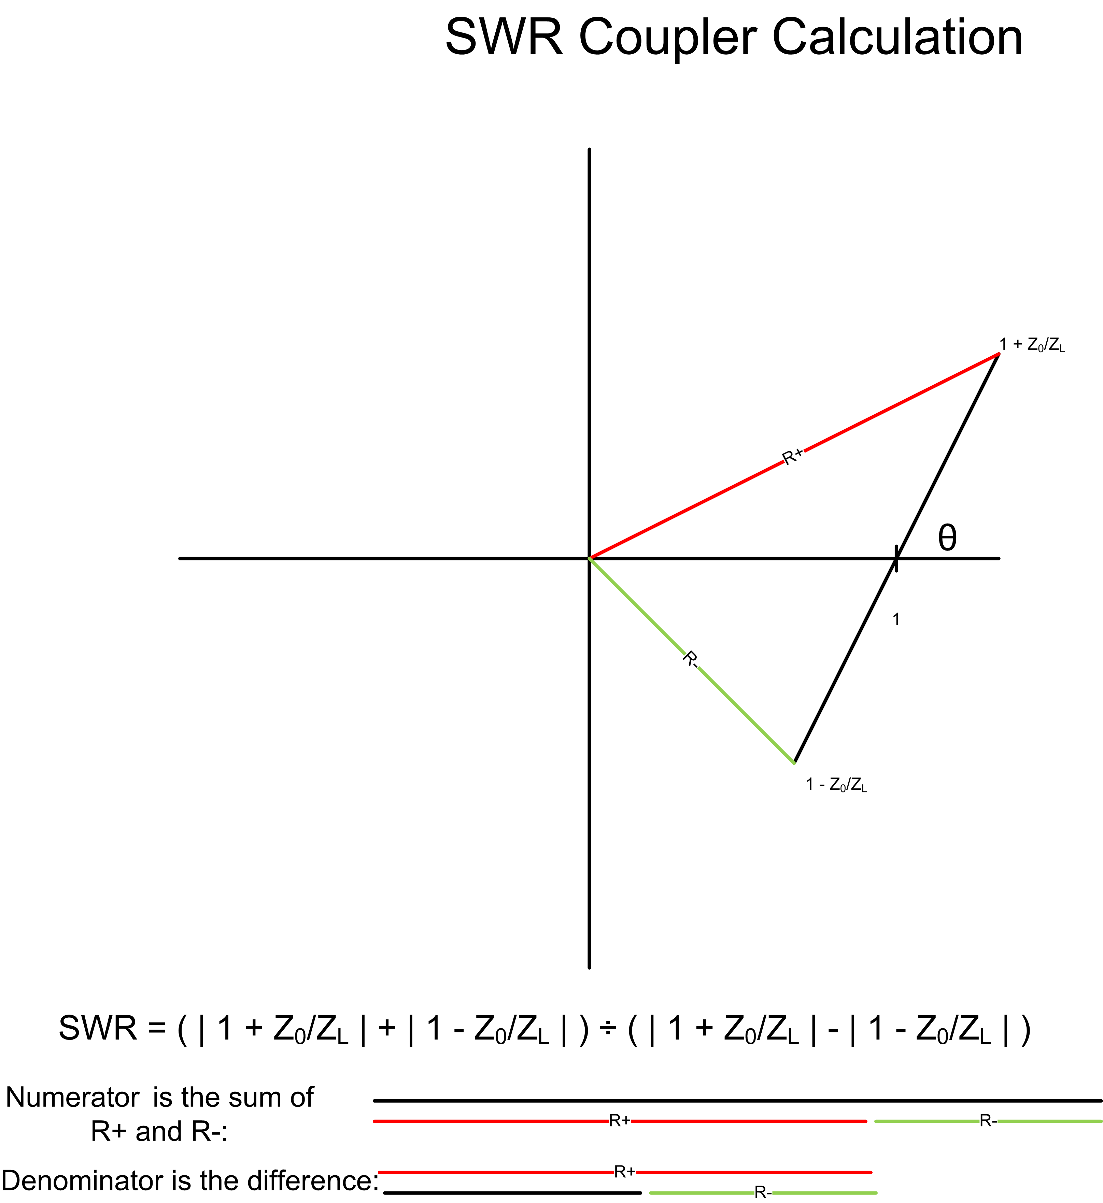
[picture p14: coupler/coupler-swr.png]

<p>Again to sanity check: consider the case Z<sub>L</sub> is purely reactive, &theta; is 90 degrees, and R+ and R- are equal length and lie
on the Y axis. The denominator of the SWR equation is zero, and the SWR infinite.</p>
<p>If Z<sub>L</sub> is purely resistive, &theta; is 0 degrees, and R+ and R- both lie along the X axis. Define Z
to be the normalized impedance (where Z = 1 means Z<sub>0</sub>=Z<sub>L</sub>), then, for Z > 1, R+ is of length 1 + Z and R- is of length Z - 1, 
and the SWR works out to be Z. Similarly, if Z < 1, the SWR works out to be 1/Z. In prose, for a resistive load impedance, the SWR is the ratio of the load and the characteristic impedance, taking the larger in the numerator.</p>
<p>The diode/capacitor detectors
produce the peak voltage, and have a driving impedance of 50 ohms
from the point of view of the ADC's in the coupler.</p>
<p>The code in the sketch implements the above SWR equation after first implementing
a correction for the non-ideal diode.</p>

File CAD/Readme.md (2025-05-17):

# CAD Notes
Solid models are presented for:
<ul>
<li>The OEM console retrofit. A pair of 3D printed parts is presented. 
<li>The custom coupler that you'll need if you don't have one from Nye Viking
<li>A work-alike console you can construct if you want a Nye Viking Power Meter and you
don't have a Nye Viking OEM console.
</ul>
<p>The CAD layout was done with <a href='https://resources.sw.siemens.com/en-US/download-solid-edge-community-edition'>Solid Edge Community Edition</a>.
All the models are exported in STEP format, which is supported by many 3D modeling tools and
3D printer slicers.</p>
<p>In the console folder are three different console designs. <code>console2.asm</code> is
the recommended design and is what is in the photographs.</p>
<p>The one in console.asm is complete
in the sense that if you print all its parts, you can assemble a Nye Viking workalike. I am
not satisfied with its cosmetics and have a console3.asm layout in that folder that, as of this
writing, is simply a concept. The console3 design does not have printable 3D parts.
<p>The coupler design has one 3D printed part, a spacer to 
make more clearance for the 4-pin connector solder lugs. And it is useful as a template for
a drilling template for the necessary holes in the Hammond Aluminum box.</p>

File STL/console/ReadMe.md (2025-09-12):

# Power Monitor work-alike 3D printed console
The console prints in four parts. Each STL is oriented for FDM printing as published. 
The front panel and back panel are designed
to accommodate a filament color change at Z = 1.2mm in order to acheive a different color background for the
text labels on those panels. The text prints better with a smaller than standard nozzle diameter.
I used 0.3mm.

The sub-panel part is prone to warping while being 3D printed. A brim helps control that, although it also makes post print
processing a nuisance.

<h3>Assembly</h3>
<p>The sub-panel has a press-in hex fitting on each of its sides for a #12-28 (fine thread) nut that holds the console to
a pivoting mount. Tap them in with a hammer. (The
OEM console uses M5 hardware for its pivot mount. Why it has one bit of metric hardware with imperial
everywhere else is a mystery for the ages.) The potentiometer and the 3-way switch attach to 
their respective holes in the front panel. Each requires 3 wires to
the PCB. Disassembly will be much easier later if you use connectors at the PCB. I terminated 
those wires in a 3 pin header. The PCB has
0.1" spacing for its end. The 12V LED strip for meter back light has a self adhesive into the top channel
of the front panel. Its two wires should be terminated in a 2 pin header, spaced 0.1" as well. Five #4 square
nuts go in the four corner channels of the front panel plus one in the middle between the meters. They
should press fit and stay in place, but, if not, use a bit of cellophane tape to keep them from falling
out as the front panel is handled later.</p>
<p>The PCB fastens to the back panel with two #4 machine screws and two 3/8" #4 hex nuts. 
Also on the back panel are recesses for two #6 hex nuts that will be
used later to fasten the back panel to the sub panel.</p>

Each meter fastens to its holes in the sub panel. Each has four screw posts, but a nut on only two
of the four is plenty. With the meters, the potentiometer, and the 3-way switch LED back light, and #4 square nuts all assembled,
the front panel 
fastens to the sub panel with quantity five #4 x 3/8" screws. 

The back panel, with the PCB assembled to it and hex nuts pressed into the appropriate recesses, slides into
the sub panel. Before fastening with #6 by 5/16" screws through the bottom of the sub panel, fit the lid into 
position on the top and then the whole assembly can be held together in one had while the two screws
are tightened from the bottom. I used black phillips head #6 screws.

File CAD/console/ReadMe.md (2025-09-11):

# 3D model for work-alike console
The 3D model was done in <a href='http://freecad.org'>FreeCAD</a>. Open console.FCStd to review or modify the model.

If you're going to undertake to modify this model, you will save yourself a lot of waiting for the model
to recompute by temporarily supressing the Pad objects that print the text in both the front panel and in the back panel.
Together, those two take about 45 seconds of recompute time for every single modification I make anywhere in the model.
The Pad objects that print the text are one of the last features in the model. You'll find them.

Most of the modeling in this project is conventional, but with one exception. The pipes that route the optic fiber
threads from the front panel to the LEDs span two different Parts: the sub panel and the front panel. I struggled
in FreeCAD to find a way to share a modeled 3D path for a light pipe across two Parts. Eventually, I gave up sharing. Instead, the
light pipes are modeled in their own part, <i>light pipe design</i>, which is separate from either printable part.
The <i>light pipe design</i> volume spans both parts that will eventually contain the light pipe such that a boolean
intersection and union of the <i>light pipe design</i> with each of the other parts results in a 3D printable part
that can later be attached for a seamless light pipe. FreeCAD shows some bugs in this respect. I found it necessary
to do the intersection operation first, followed by the union. Computationally, either order should give the same
result, but FreeCAD simply gave a fatal error when I first tried the other order.

The file NyeVikingConsoleSTLs.FCMacro contains a FreeCAD macro that invokes the appropriate FreeCAD
primitives to rotate and export STL for the four parts for 3D printing. FreeCAD won't invoke the macro
from the directory it is published here in this repository. You have to bring up FreeCADs Macro menu,
figure out what folder it requires macros to be in, and relocate the FCMacro file there.

<h3>History</h3>
The FreeCAD design published here was not the first. Look back in the git history for details. Earlier designs were
done in Solid Edge, and with a PCB that had SMT LEDs along the edge of the board. I gave up on the SMT LEDs 
because it was just too easy to snap them off when handling the board during assembly. I decided to use
FreeCAD instead of Solid Edge hoping the the open source tool would work. FreeCAD definitely has its bugs,
but it eventually worked as published here.

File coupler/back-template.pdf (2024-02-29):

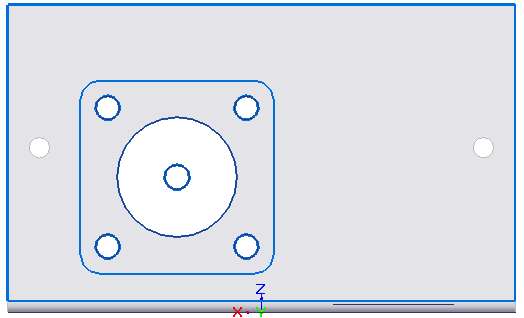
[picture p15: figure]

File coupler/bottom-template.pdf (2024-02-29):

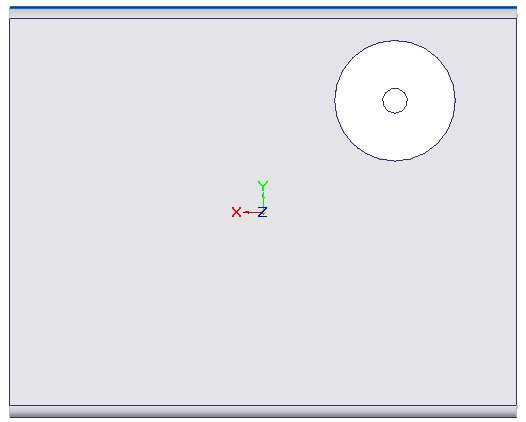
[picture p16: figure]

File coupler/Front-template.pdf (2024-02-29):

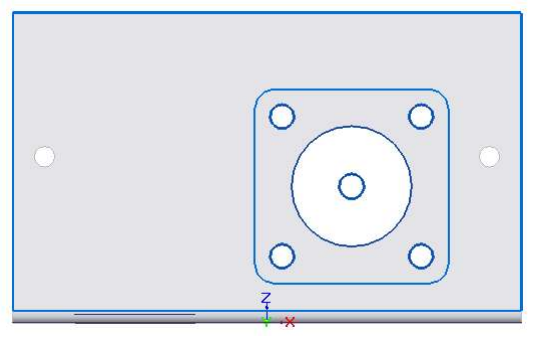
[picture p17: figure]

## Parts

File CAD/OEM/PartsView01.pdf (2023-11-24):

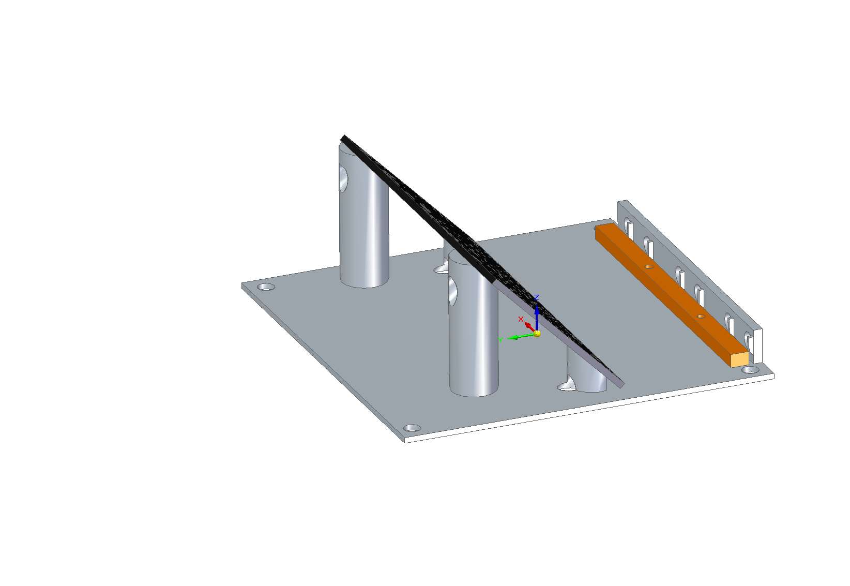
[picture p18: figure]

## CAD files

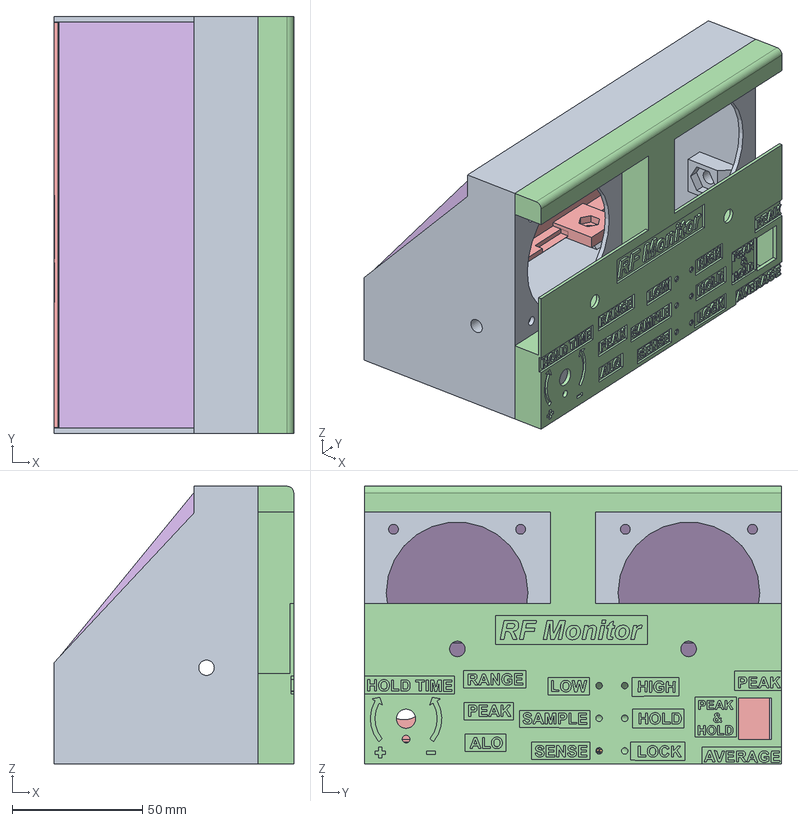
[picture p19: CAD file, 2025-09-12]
CAD/console/console.FCStd
91.9 x 159.9 x 106.4 mm
front panel body

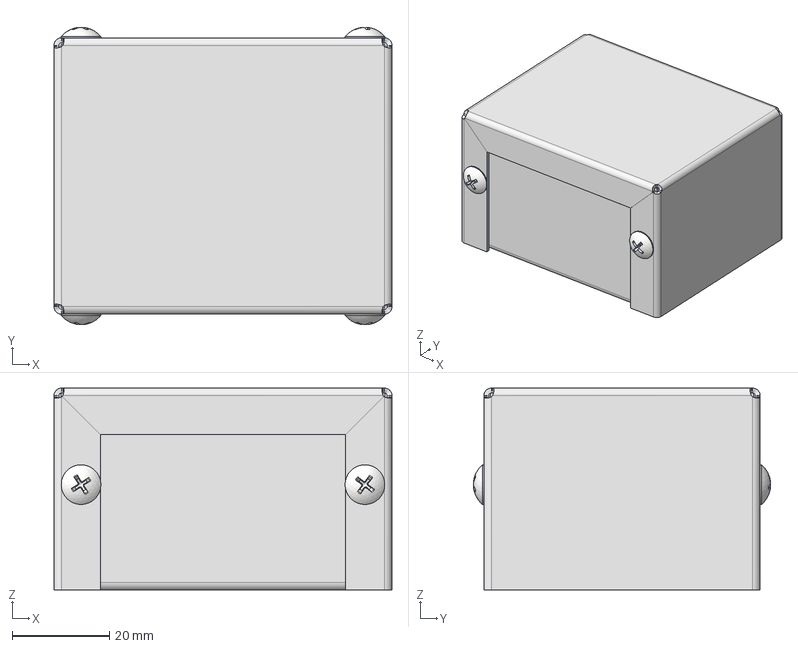
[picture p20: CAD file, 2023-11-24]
CAD/coupler/1411B.stp
69.5 x 61.1 x 41.5 mm
1411B - Bottom
1411B - Cover
Cross Recessed Truss Head Tapping Screw - Type F - Type II No. 6 - 32 - 1/4 x 4

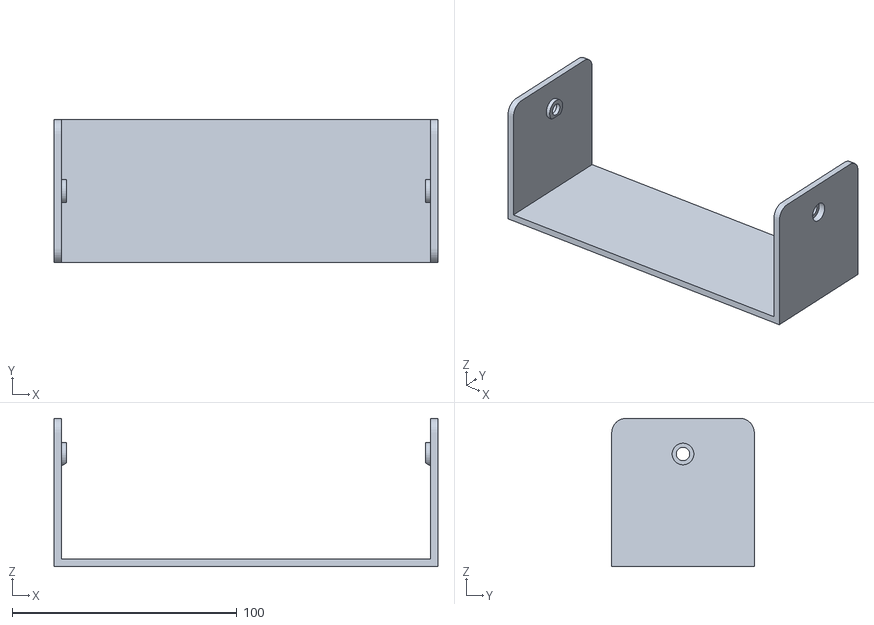
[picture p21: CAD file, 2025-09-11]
CAD/OEM/ConsoleBracket-3d.stl
171.0 x 63.5 x 66.0

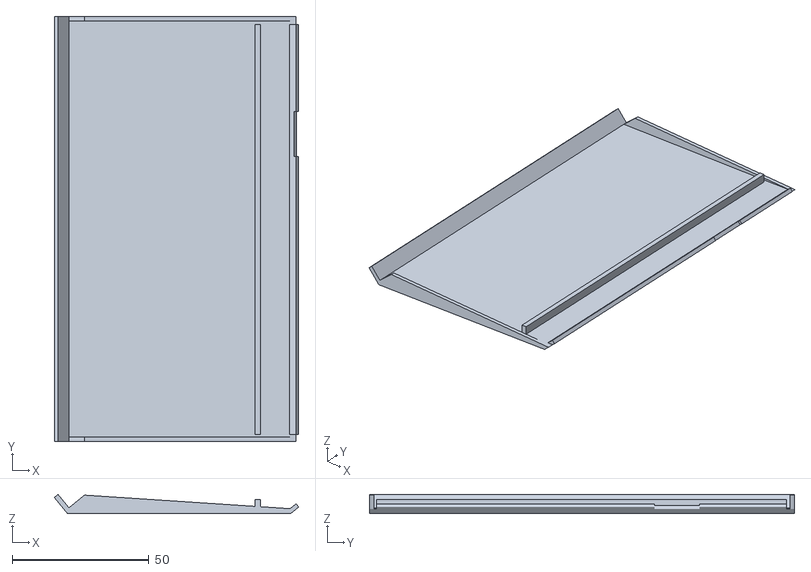
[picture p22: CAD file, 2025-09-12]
STL/console/console-lid.stl
89.5 x 155.6 x 7.02

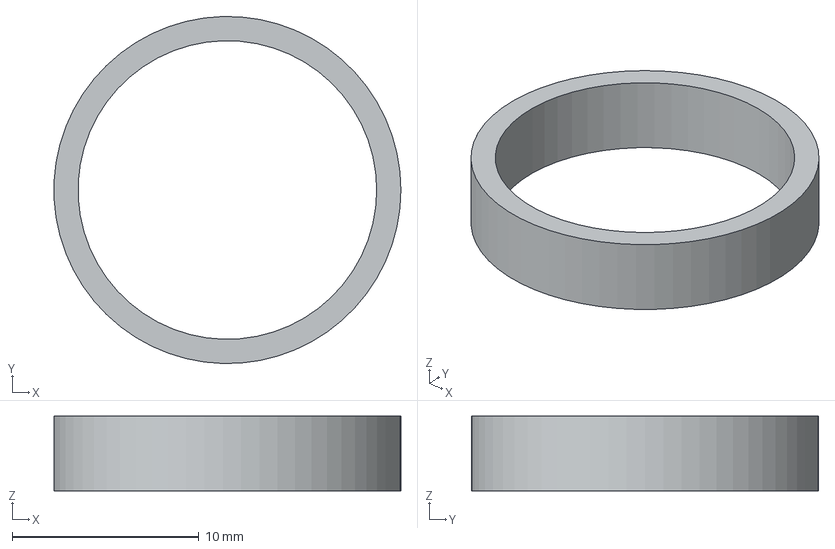
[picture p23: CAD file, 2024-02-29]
STL/coupler/CliffCon-Spacer.stp
18.6 x 18.6 x 4.00 mm

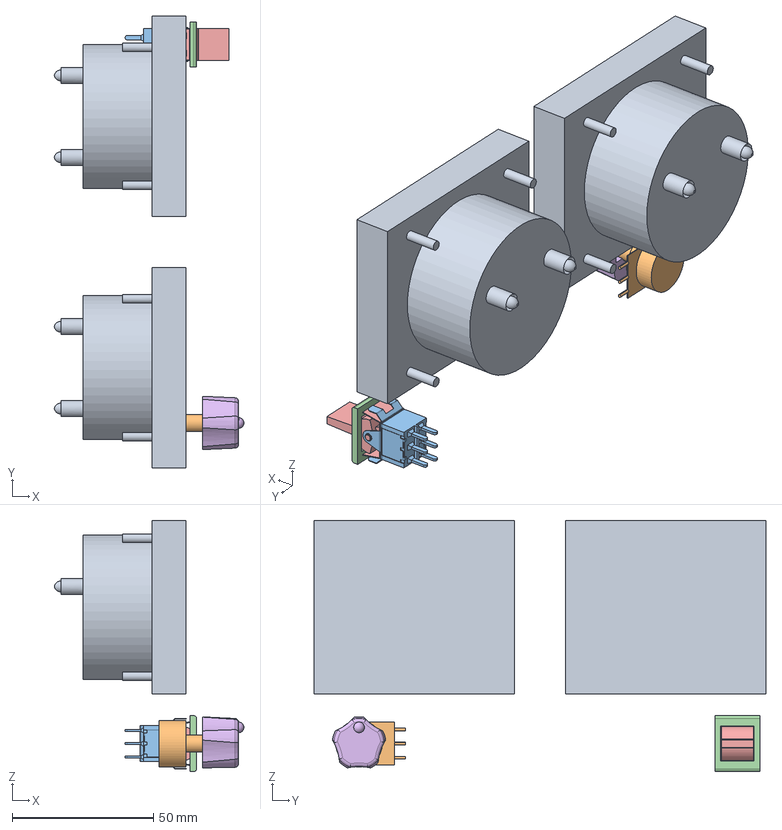
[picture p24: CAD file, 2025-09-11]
CAD/console/console-placement.FCStd
67.2 x 159.9 x 88.9 mm
meter x 2
1M-pot
300DP6R7BLKM3QEBLK
300DP6R7BLKM3QEBLK001
300DP6R7BLKM3QEBLK002
knob

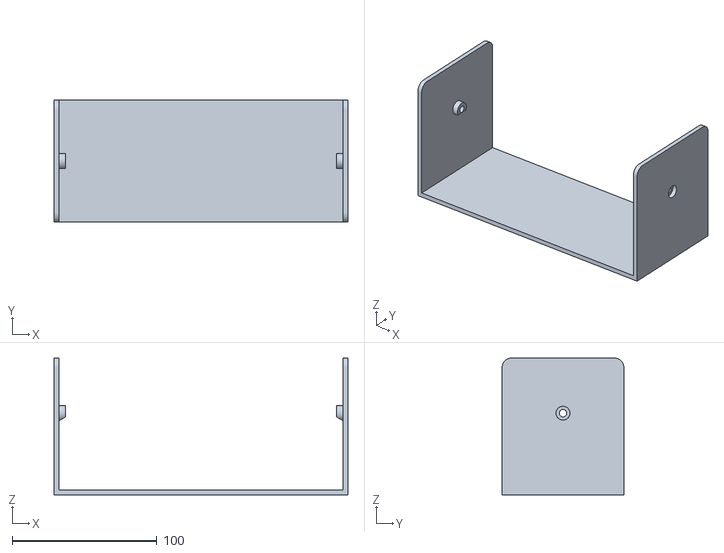
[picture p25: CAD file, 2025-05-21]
CAD/OEM/ConsoleBracket.stl
203.2 x 84.2 x 94.6

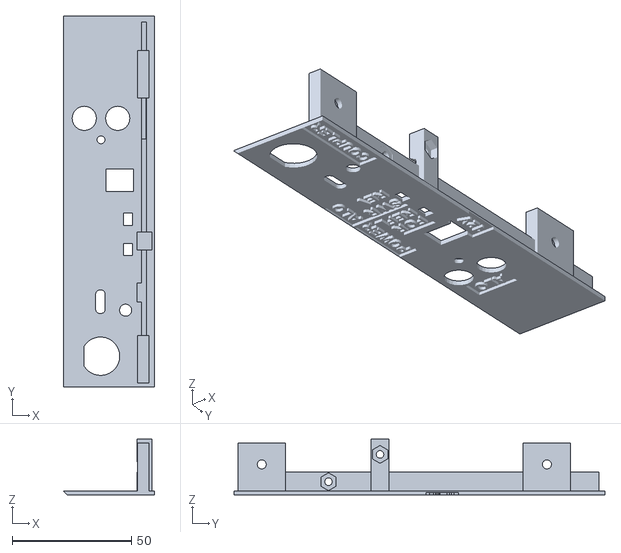
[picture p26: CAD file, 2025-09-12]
STL/console/console-back panel.stl
38.1 x 155.3 x 23.2

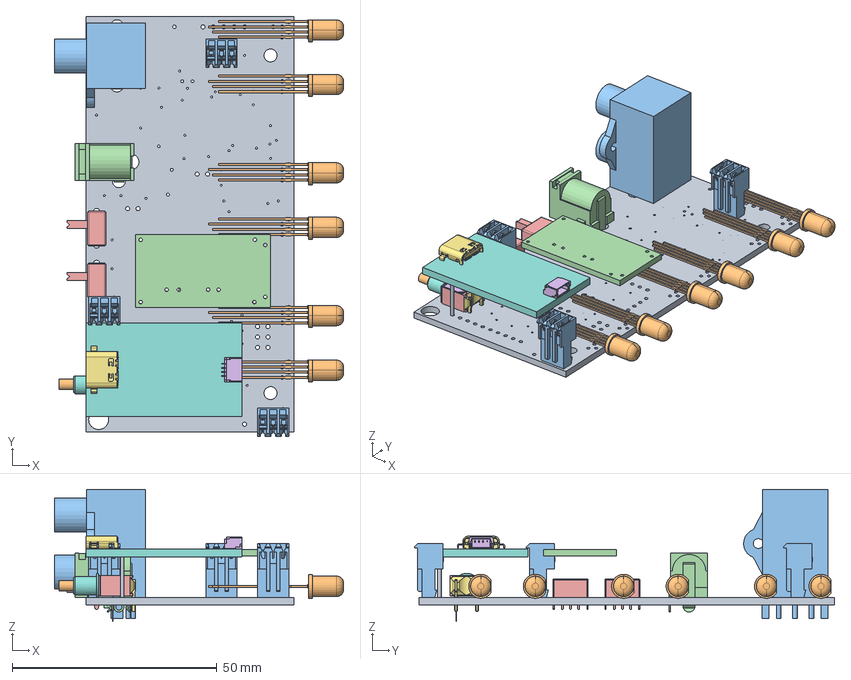
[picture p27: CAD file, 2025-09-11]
CAD/console/PCB.FCStd
70.7 x 102.7 x 32.3 mm
pcb imported
WP154A4SUREQBFZGC x 6
Dual RCA
Pro Mini
3pinconnector-640441-3 x 3
CUI_PJ-202A
SLW-864547-5A-RA-D x 2
quiik
USB-C
pcb-ft232

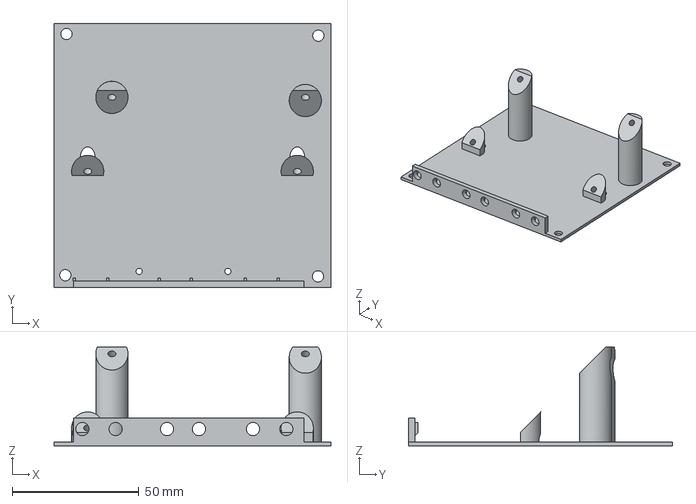
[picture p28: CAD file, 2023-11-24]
CAD/OEM/Retrofit-board.stp
109.1 x 104.0 x 38.9 mm

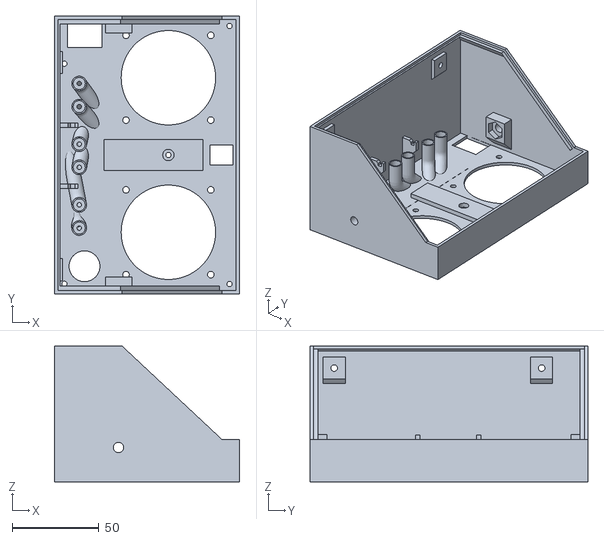
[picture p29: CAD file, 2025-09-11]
STL/console/console-sub panel.stl
106.4 x 159.9 x 78.2

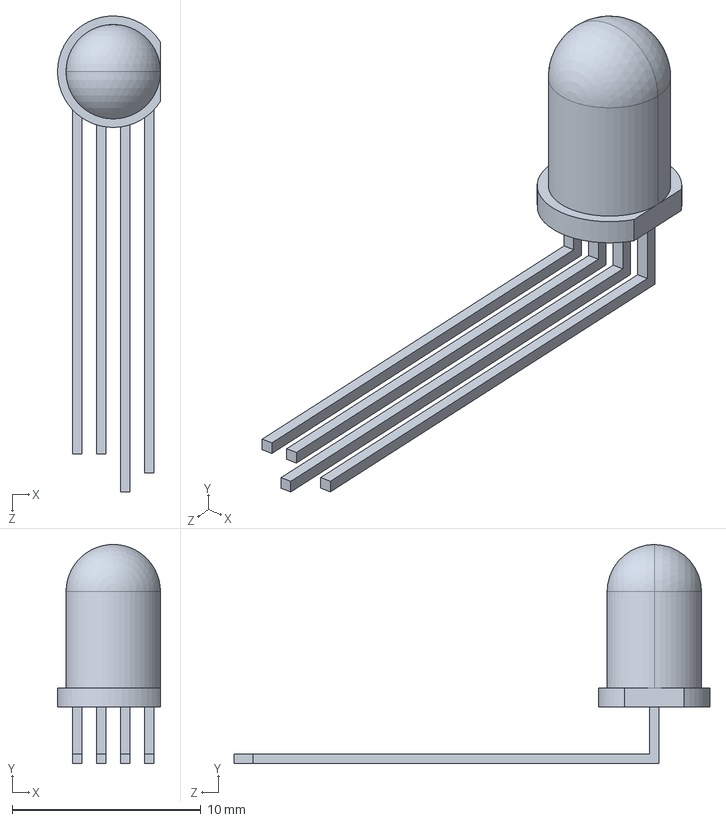
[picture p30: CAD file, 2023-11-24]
CAD/OEM/339-9-S1183.STEP
5.45 x 11.6 x 25.2 mm

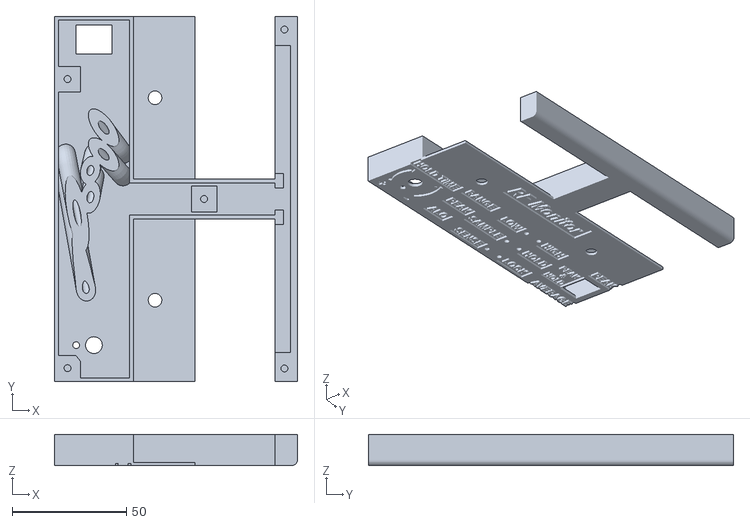
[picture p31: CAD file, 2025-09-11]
STL/console/console-front panel.stl
106.4 x 159.9 x 13.7

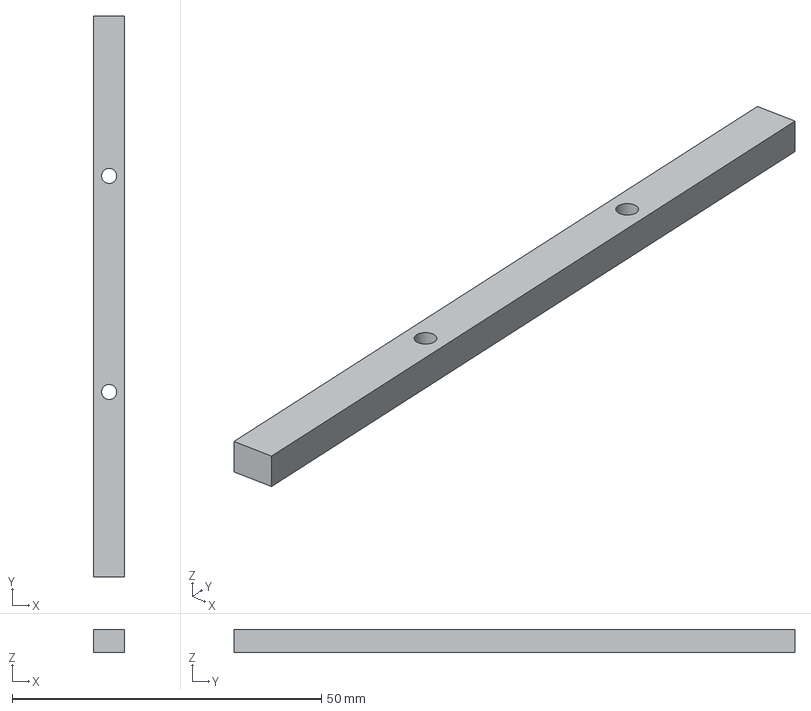
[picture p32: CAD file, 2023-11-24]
CAD/OEM/LED backstop.stp
5.08 x 90.7 x 3.75 mm

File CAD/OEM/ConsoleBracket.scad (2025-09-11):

// not metal, so thicker
BracketPrintThicknessThou = 135; 
// The plastic thickness limits pivot angle w.r.t. OEM metal brack. Make taller to compensate
BoostHeightToIncreasePivotAngleThou = 100; 

// The OEM bracket has two pivot holes. 3D print only the one you select
PivotHolePosition = "bottom"; // [bottom, top]

/* [Console Measurements] */
BracketHeightThou = 3625; 
BracketWidthThou = 8000;    // measured
BracketDepthThou = 3313;    // measured
ConsoleWidthThou = 7563; // measured
// from top of bracket
Hole1ZoffsetThou = 1500; 
// from top of bracket
Hole2ZoffsetThou = 438; 
// OEM console is threaded M5
HoleDiameterThou = 200; 
// OEM is M5
HeadDiameterThou = 380; 
// OEM is M5
HeadThicknessThou = 135; 
PivotThreadRecessDepthThou = 90; // measured

/* [Units for display and STL] */
mmPerThou = .0254; // [0.0254:mm, 1:thou]

module __none__() {}

// measured...
PivotThreadRecessDiameterThou = 457; // measured
BracketTopRoundRadiusThou = 250;    // measured

BracketCompensatedHeightThou = BracketHeightThou + BoostHeightToIncreasePivotAngleThou;

PivotHoleZThou = PivotHolePosition == "bottom" ? (BracketCompensatedHeightThou - Hole1ZoffsetThou) : (BracketCompensatedHeightThou - Hole2ZoffsetThou);



echo ("Console screw head clearance = ", 0.5*(BracketWidthThou - ConsoleWidthThou) - BracketPrintThicknessThou, " thou");

module mount()
{
    difference()
    {
        diam = PivotThreadRecessDiameterThou * 0.9;
        peg = PivotThreadRecessDepthThou + 0.5*(BracketWidthThou - ConsoleWidthThou);
        cylinder(h=peg, d=diam);
        translate([0,0,BracketPrintThicknessThou])
        translate([diam/2,-diam/2])
        rotate([0,-30])
        cube([peg, diam, diam]);
    }
}

scale(mmPerThou)
{
    PivotYPos = BracketDepthThou/2;
    difference()
    {
        union()
        {
            difference()
            {
                profile1=[[0,0], [0,BracketDepthThou], [BracketCompensatedHeightThou, BracketDepthThou], [BracketCompensatedHeightThou,0]];
                profile2=[[0,0], [0,BracketDepthThou], [BracketTopRoundRadiusThou, BracketDepthThou], [BracketTopRoundRadiusThou,0]];
                translate([BracketWidthThou,0,0])
                rotate([0,-90])
                linear_extrude(height=BracketWidthThou)
                {
                    offset(BracketTopRoundRadiusThou)
                    offset(-BracketTopRoundRadiusThou)
                        polygon(profile1);
                    polygon(profile2);
                } 
                translate([BracketPrintThicknessThou, -1, BracketPrintThicknessThou])
                    cube([BracketWidthThou - 2 * BracketPrintThicknessThou, BracketDepthThou+2, BracketCompensatedHeightThou]);
            }

            translate([0, PivotYPos, PivotHoleZThou])
                rotate([0,90])
                    mount();
            translate([BracketWidthThou, PivotYPos, PivotHoleZThou])
                rotate([0,90, 180])
                    mount();

        }

        translate([0, PivotYPos, PivotHoleZThou])
        {
            translate([BracketWidthThou,0])
            rotate([0,-90])
            {
                cylinder(h=BracketWidthThou, d = HoleDiameterThou);
                cylinder(h=HeadThicknessThou, d = HeadDiameterThou);
            }
            rotate([0,90])
                cylinder(h=HeadThicknessThou, d = HeadDiameterThou);
        }  
    }
}

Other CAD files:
STL/OEM/LED backstop.stl
STL/OEM/Retrofit-board.stl

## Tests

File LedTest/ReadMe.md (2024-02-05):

# LED Test sketch
This sketch has commands on its serial port to test the connections on the PCB.
See the file <code>LedTest.ino</code> for instructions.

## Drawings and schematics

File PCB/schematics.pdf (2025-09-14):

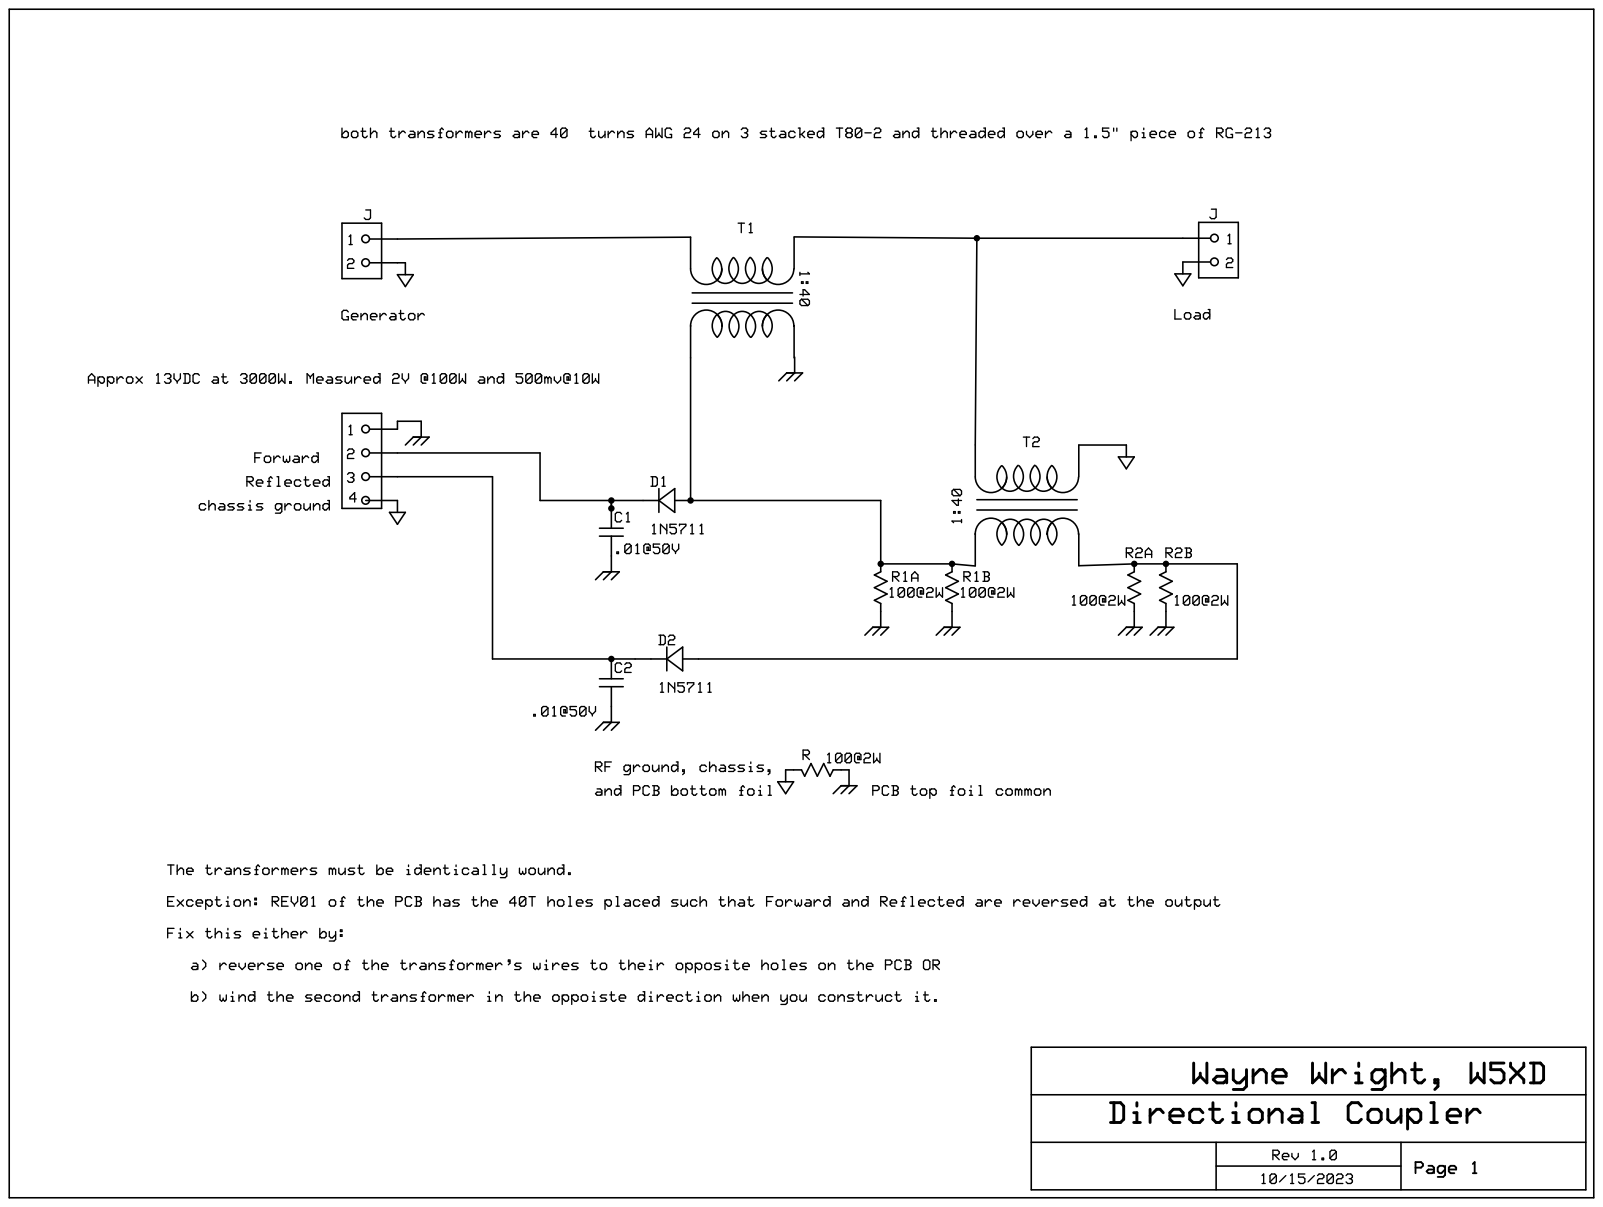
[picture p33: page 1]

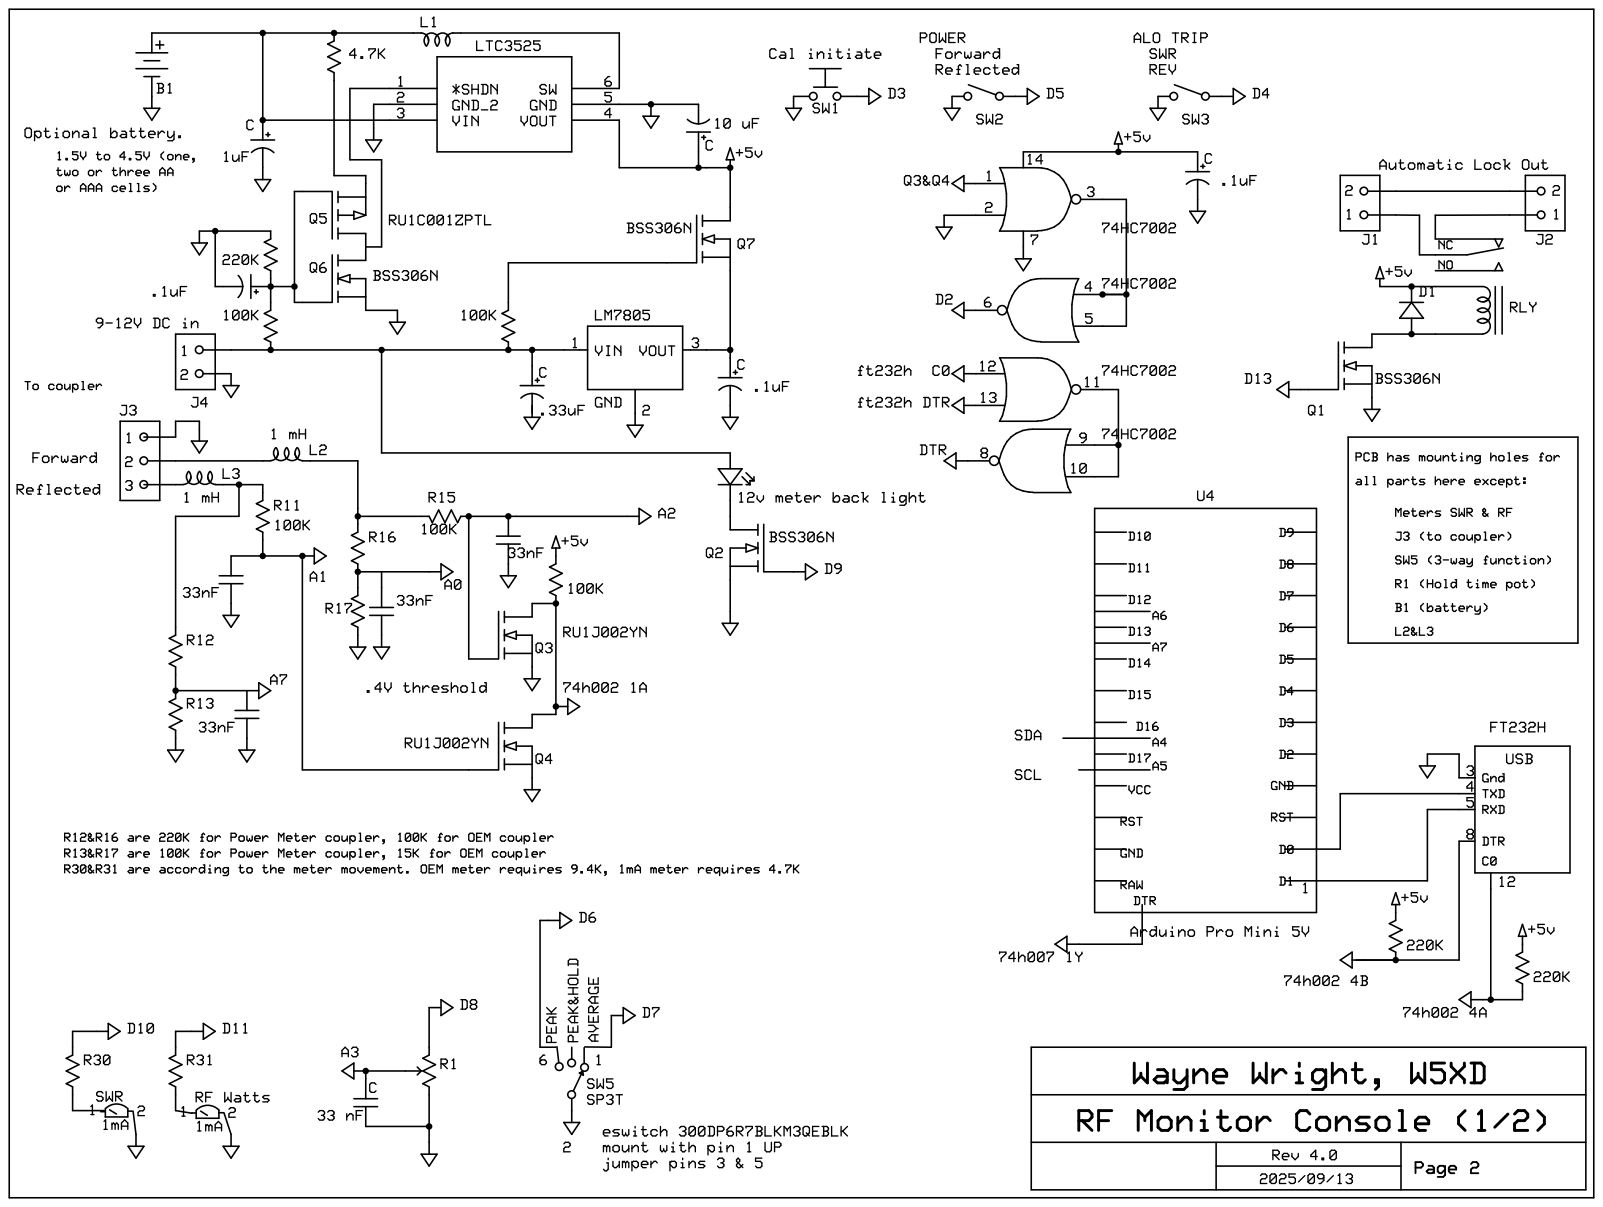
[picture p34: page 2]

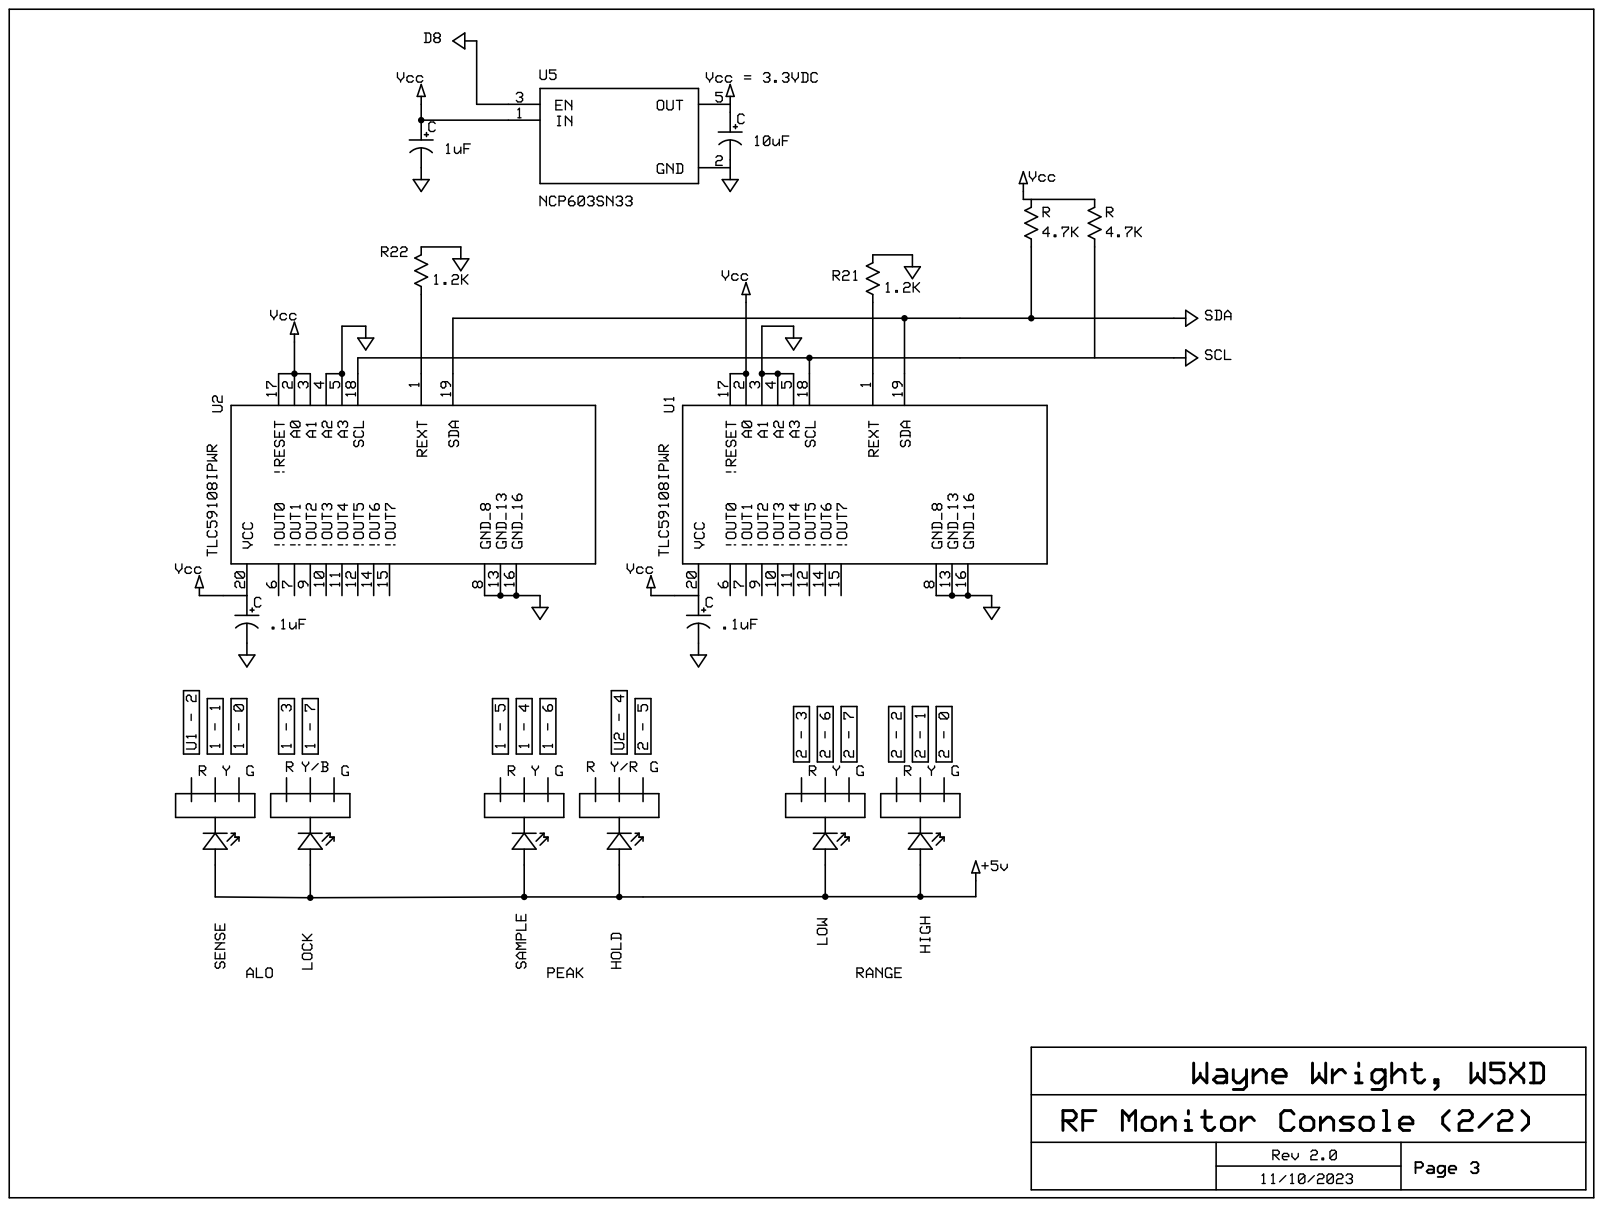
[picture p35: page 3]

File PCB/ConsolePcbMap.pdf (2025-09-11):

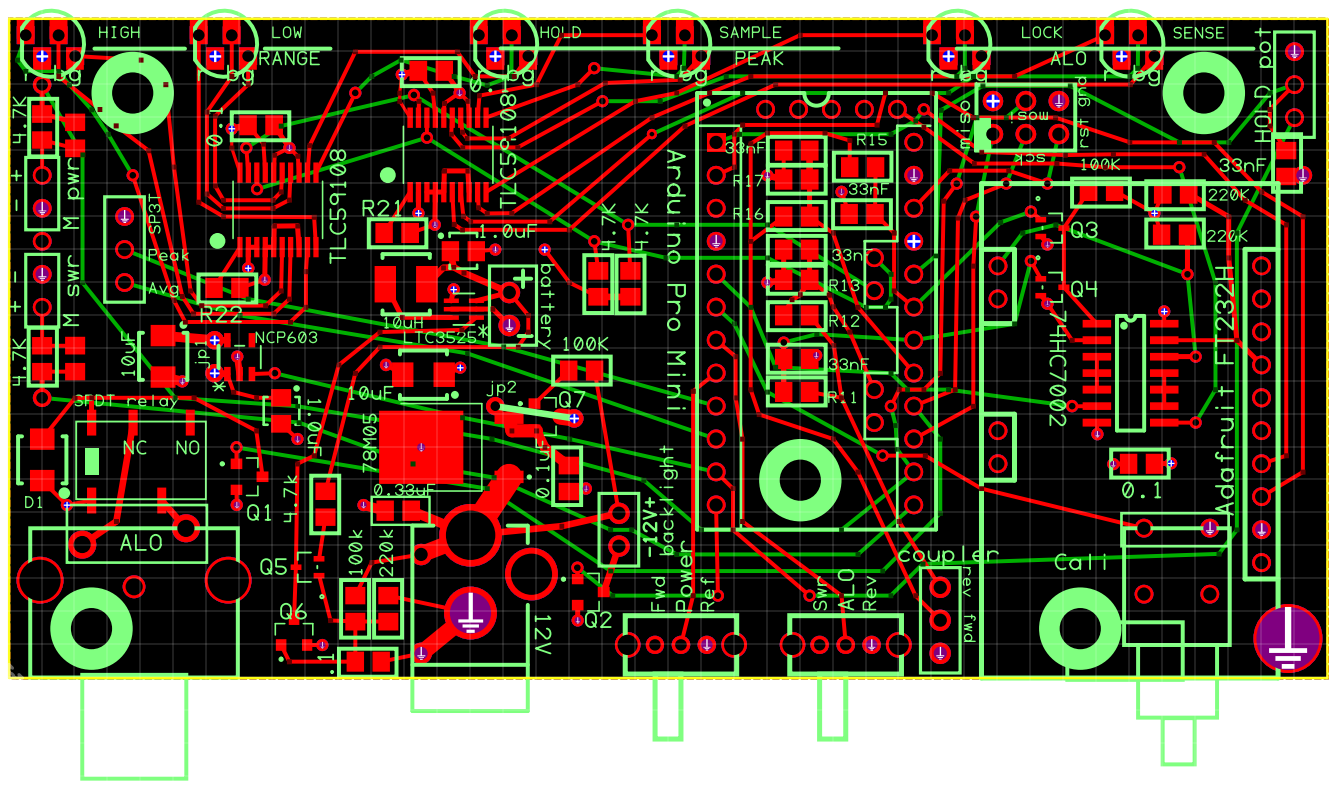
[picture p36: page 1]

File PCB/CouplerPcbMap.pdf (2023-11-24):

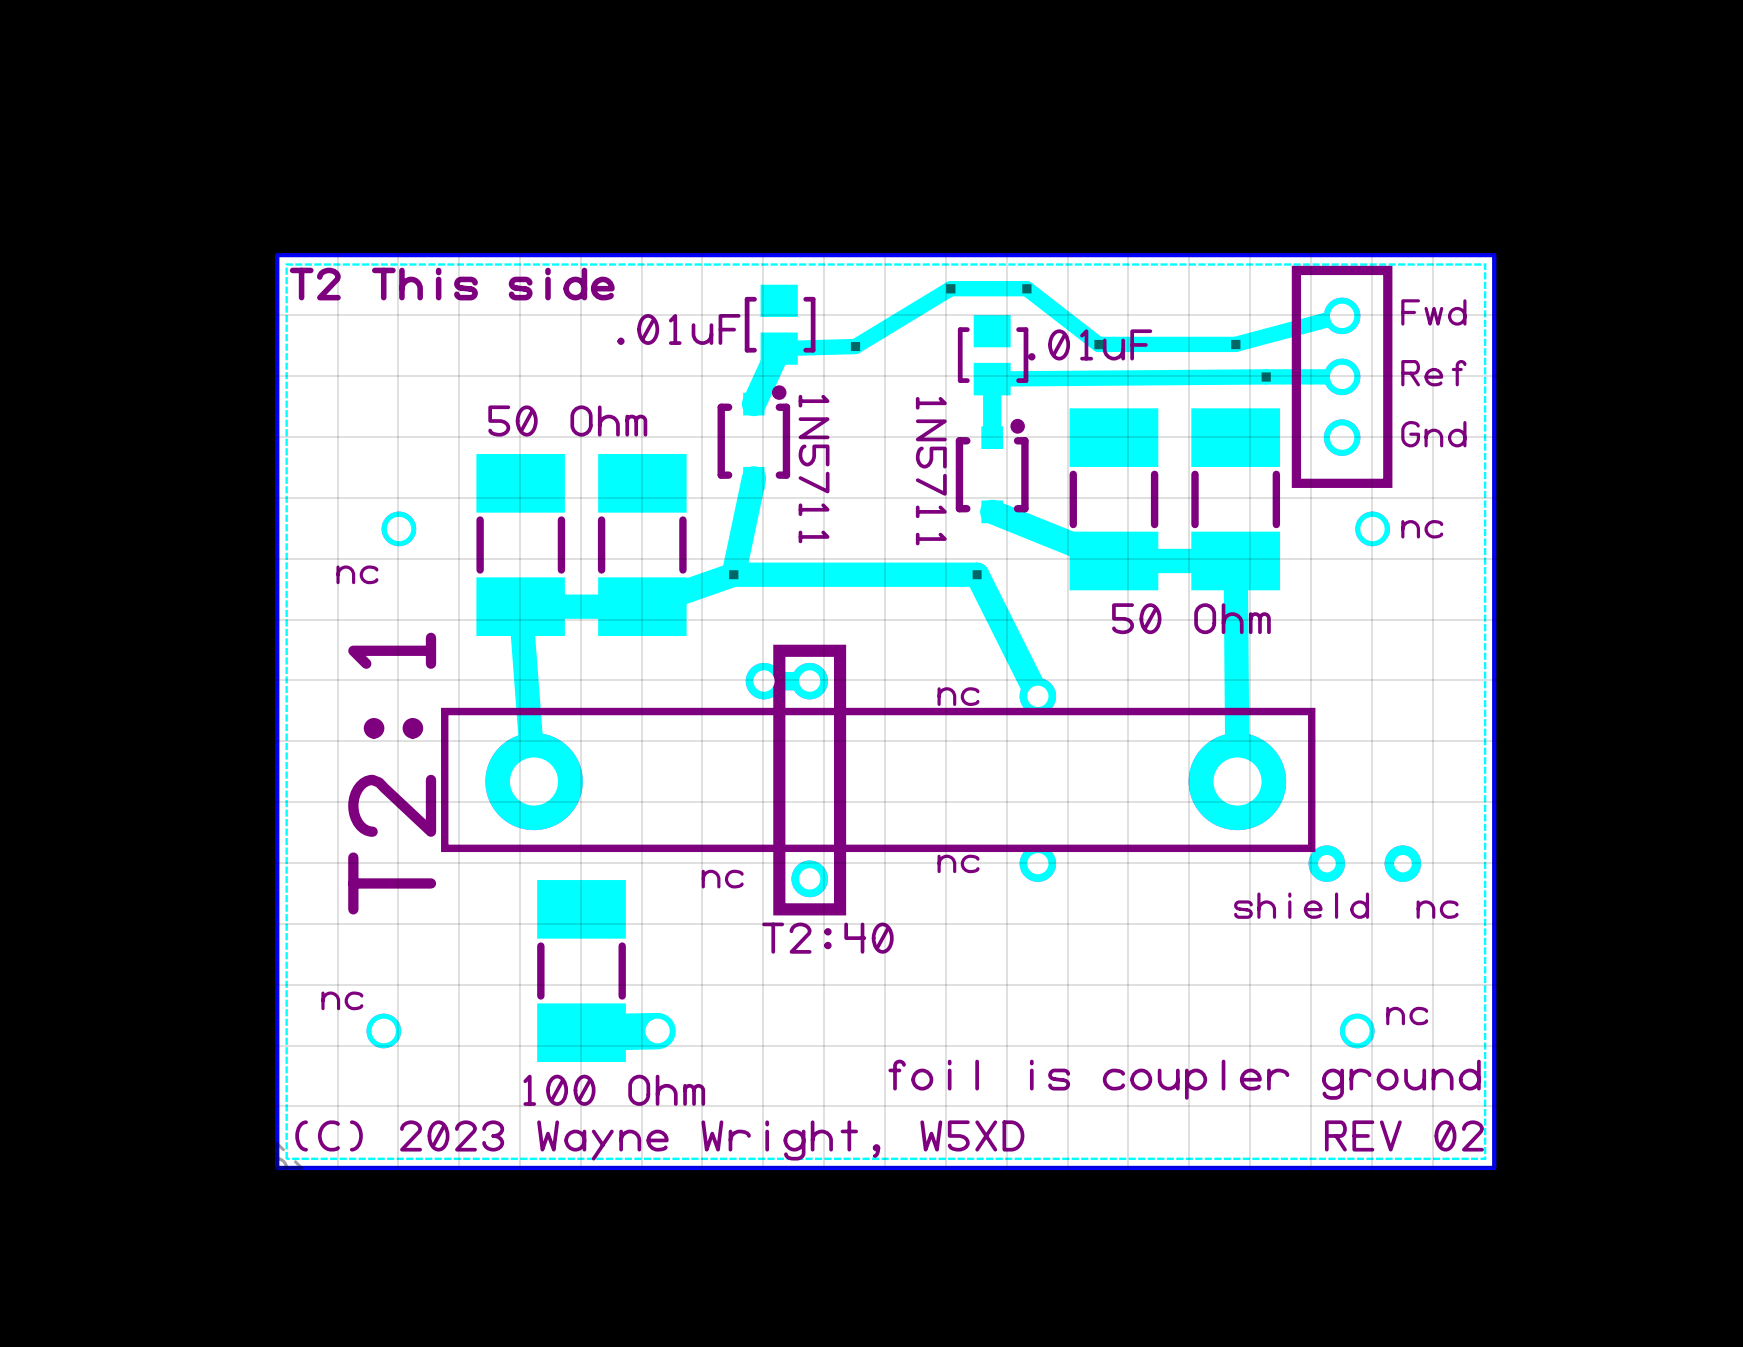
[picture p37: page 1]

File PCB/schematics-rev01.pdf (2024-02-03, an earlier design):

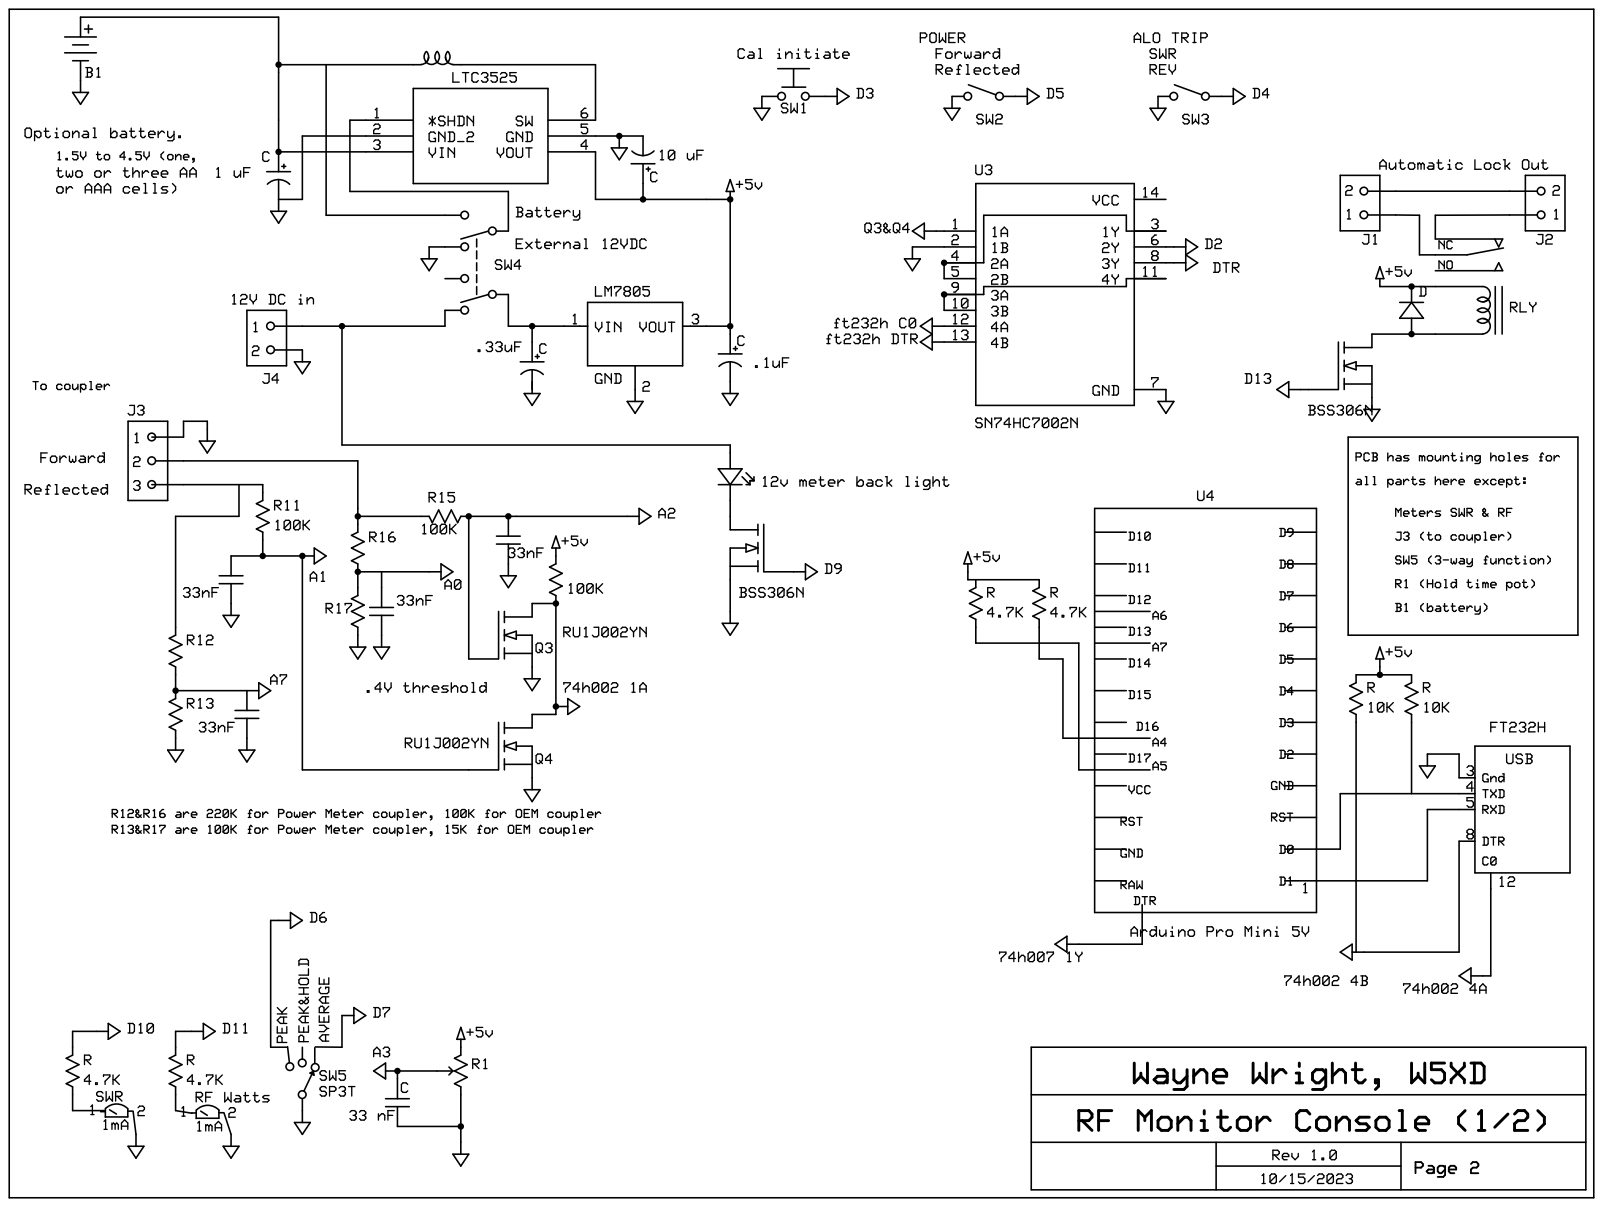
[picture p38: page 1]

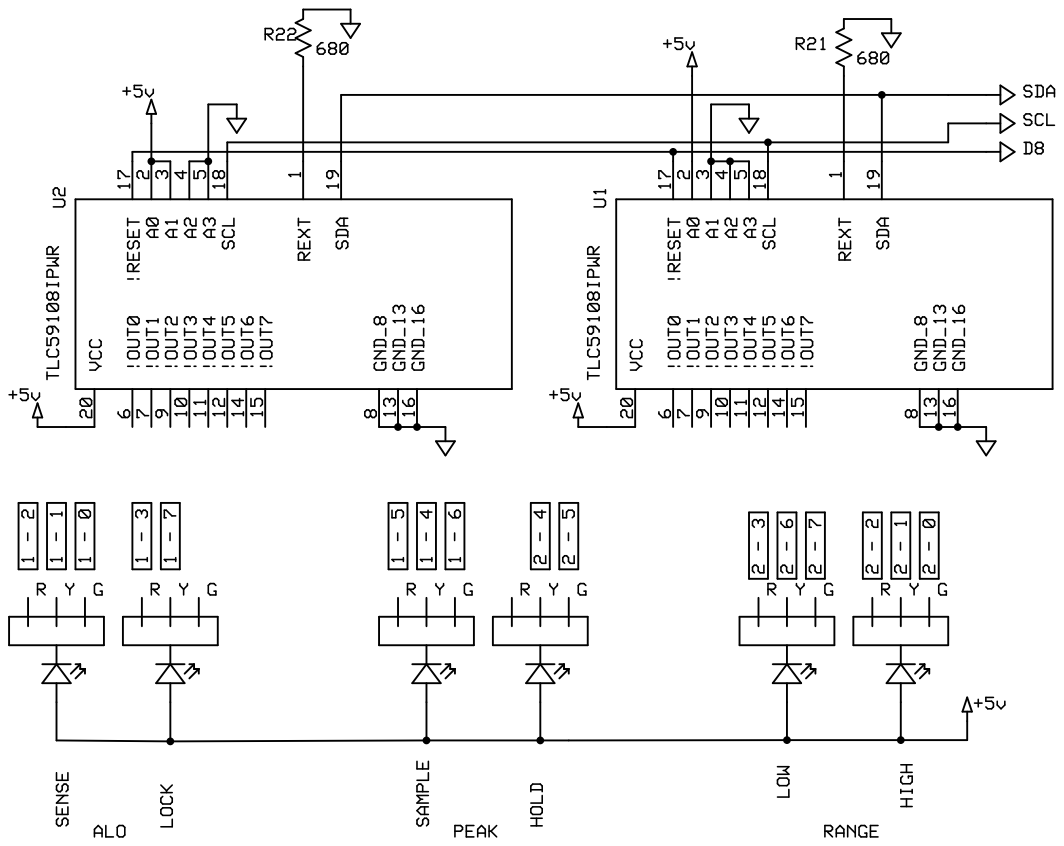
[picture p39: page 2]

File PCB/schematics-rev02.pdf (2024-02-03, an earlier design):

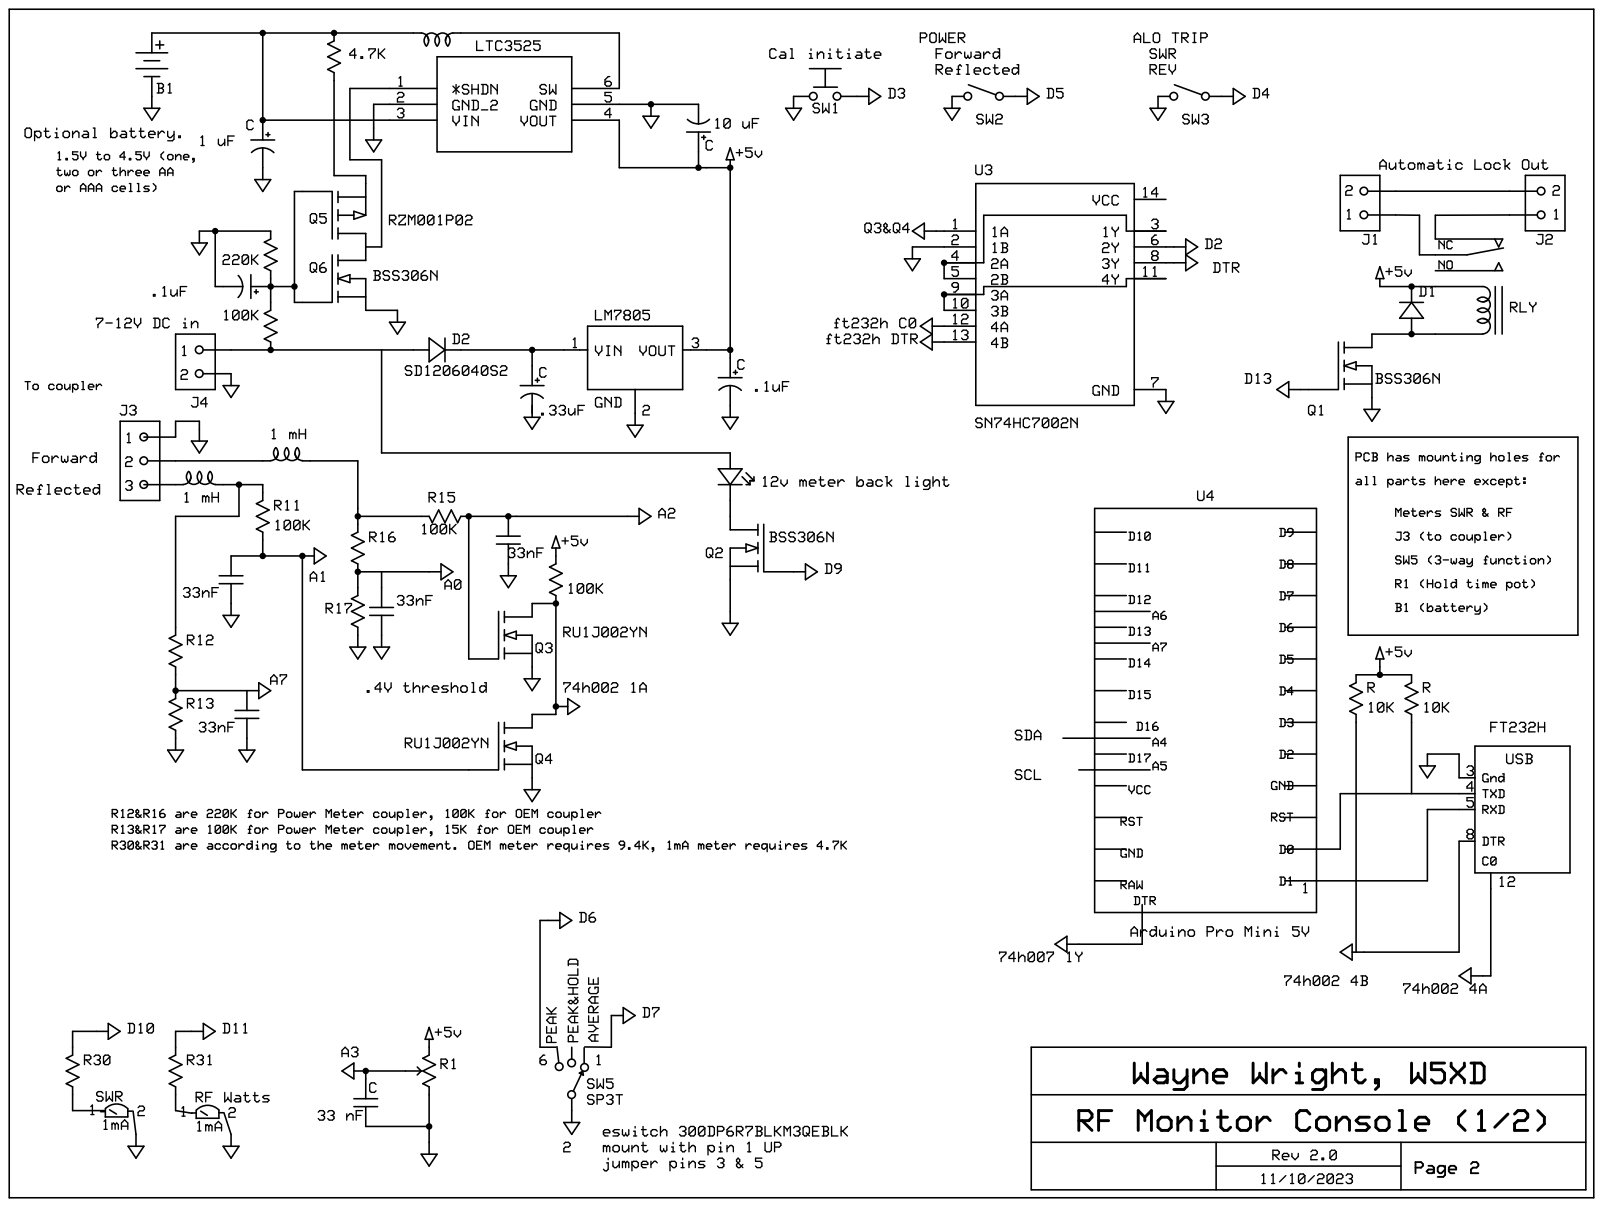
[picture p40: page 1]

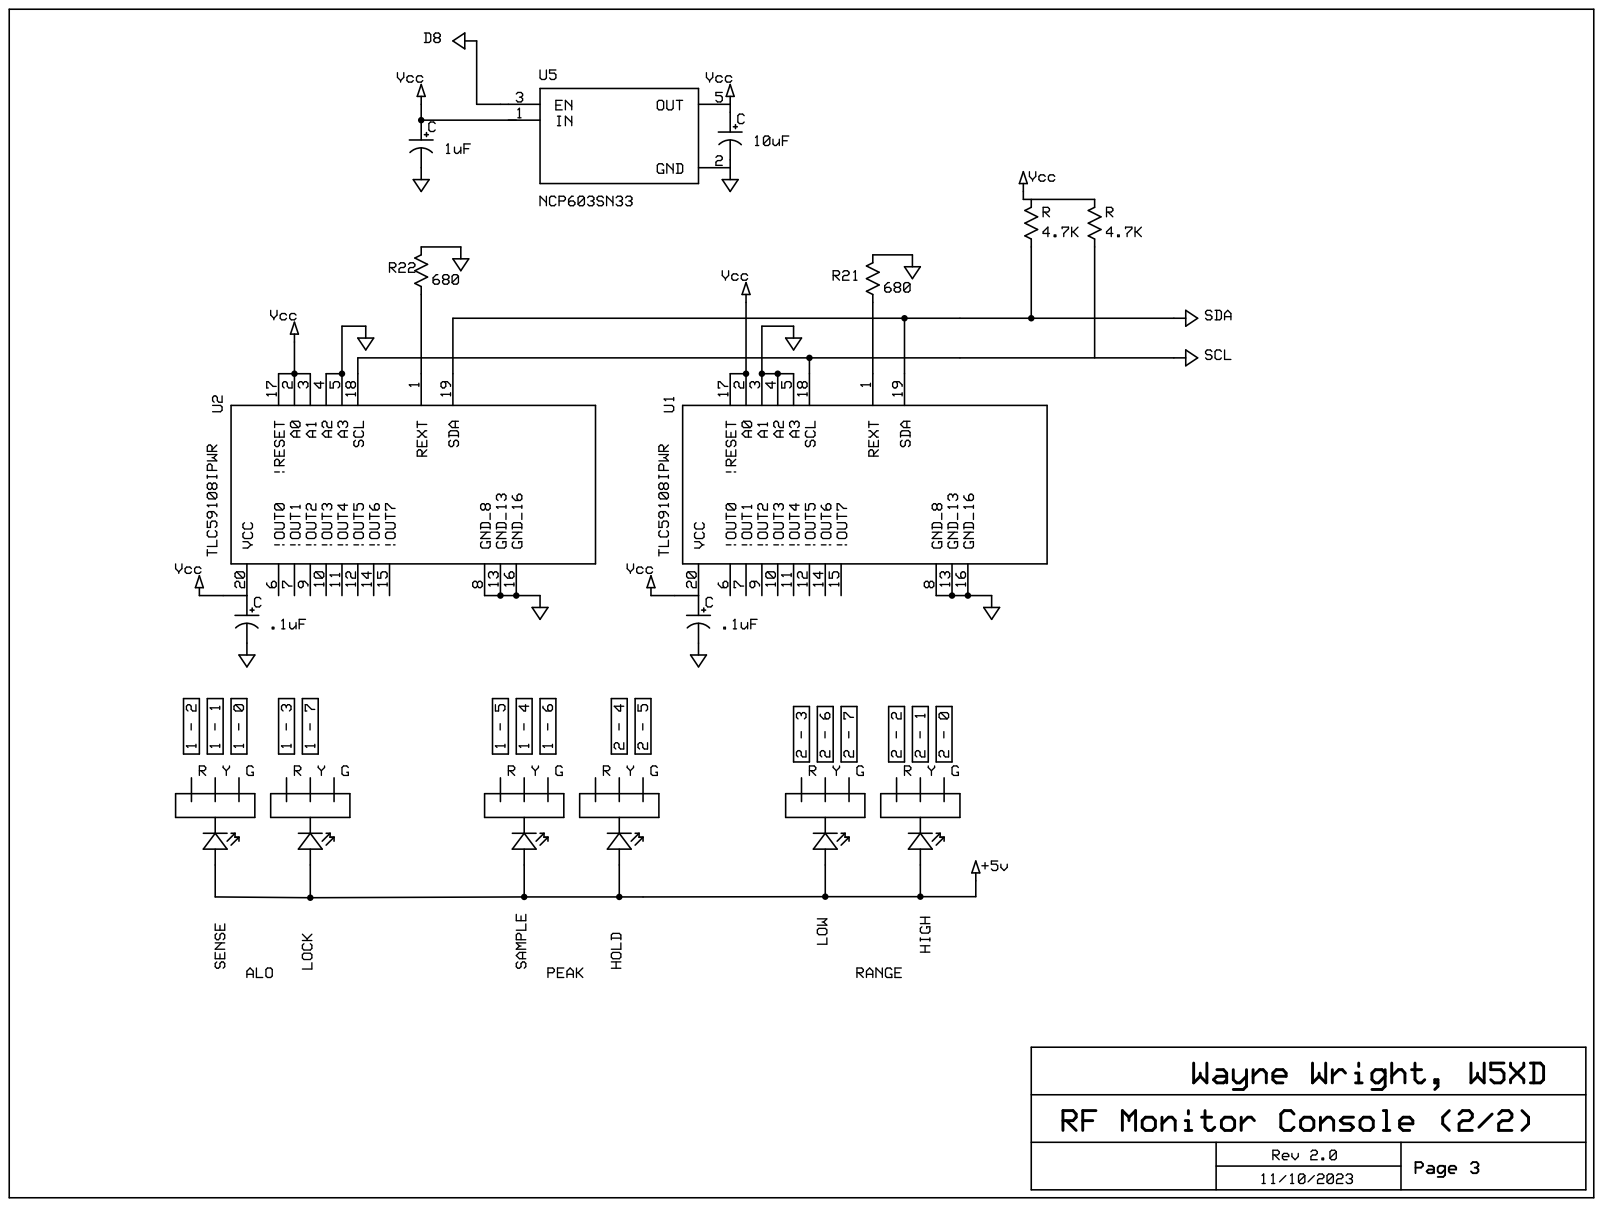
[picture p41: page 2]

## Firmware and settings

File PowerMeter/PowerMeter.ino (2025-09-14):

/* Copyright (c) 2025 by Wayne E. Wright
 ** W5XD
 ** Round Rock, Texas, USA
 **
 ** For terms of use, see LICENSE
 */
#include <avr/pgmspace.h>
#include <avr/sleep.h>
#include <avr/interrupt.h>
#include <avr/power.h>
#include <avr/wdt.h>
#include <EEPROM.h>

#include "PowerMeterLEDs.h"

static_assert(sizeof(uint16_t)==2,"uint16_t");
static_assert(sizeof(int16_t)==2, "int16_t");
static_assert(sizeof(uint32_t)==4, "uint32_t");
static_assert(sizeof(int32_t)==4, "int32_t");
static_assert(sizeof(uint64_t)==8, "uint64_t");

#define POWER_METER_INO_VERSION_STR "3.0"

/* Nye Viking RF Power Meter
 * Behaves like the original analog circuit board, but on Arduino. This code was tested with the RFM-003, the 3000W model.
 * This sketch runs on an Arduino Pro Mini installed in either of two hardware configurations:
 * a) On the PCB (also documented in this repository) installed in an RFM-003 in place of the OEM analog board
 * ...OR...
 * b) On the PCB installed in an enclosure designed to mimic the OEM enclosure. 
 * 
 * Compile time #define's distinguish the arithmetic constants needed in these hardware options:
 * a) the OEM coupler 
        versus a home built coupler documented in this repo 
        (arithmetic differs from ADC to Power and SWR)
 * b) The front panel meters in the OEM console 
        versus custom meter faces (documented here) installed in a 0-1mA meter movement
        (lookup tables for PWM values to SWR and Power differ)
 * c) RGB LEDs for the front panel 
        versus RGY.
        (which LED gets turned on when differs)
*  d) Watchdog timer support. This is an optional feature requiring progamming the Arduino with an ISP and giving more reliability.
 */

// Use one of the following two. 
// Affects the arithmetic calculating power/SWR from the ADCs
#define OEM_COUPLER // The OEM coupler, which, in turn requires a 15/115 input voltage divider at R12/R13/R16/R17
//#define W5XD_COUPLER // The coupler in ths report, wich requires a 100/320 voltage divider

// Use one of the following two
#define OEM_METER_SCALES  // the meters are series resistor with PWM=250 is full scale, as painted by Nye Viking
//#define CUSTOM_METER_SCALES // the meters are series resistor with PWM=250 is full scale, with meter face backings printed per this repo

/* The above two compile directives switch between look up table entries. Those look up tables are part of
** the elimination of any need floating point at run time, and any need for trig or log functions.
** We do end up with some 32 bit and 64 bit long integer arithmetic, including divides, but floating point
** is avoided by using the two fixed point integer typedef's below, AcquiredVolts_t and DisplayPower_t. */


// There is also the LEDS_ARE_RGB compile time option in PowerMeterLEDs.h

//#define SUPPORT_WDT /* READ THE PARAGRAPH BELOW*/

/* do NOT enable the SUPPORT_WDT symbol when using the Pro Mini with its default boot loader.
** If you do not know what "default boot loader" means, then also do NOT enable SUPPORT_WDT
** The issue is that the standard boot loader does not support watchdog timer (WDT) reset.
** What does this mean?
** The WDT support is a backup for the case something goes horribly wrong in the sketch code below.
** It "resets" the arduino. But if the default boot loader is what is in FLASH on the Arduino
** Pro Mini (and it WILL BE unless you have used a programmer to change it) then the WDT makes
** any such problem worse. You will not get control of the Power Meter again without removing all power.
** That includes removing the battery backup! You'll have to open the enclosure and pull one of the
** AA cells. The author used a programmer ("Arduino as ISP") to replace the bootloader with the
** optiboot loader. That requires changes to boards.txt in the Arduino IDE and, of course,
** access to an Arduino as ISP programmer. */

#ifdef OEM_COUPLER
#define COUPLER_BUILD_STR "OEM COUPLER"
#endif
#ifdef W5XD_COUPLER
#define COUPLER_BUILD_STR "W5XD COUPLER"
#endif
#ifdef OEM_METER_SCALES
#define METER_BUILD_STR "OEM METER SCALES"
#endif
#ifdef CUSTOM_METER_SCALES
#define METER_BUILD_STR "W5XD METER SCALES"
#endif


typedef uint16_t AcquiredVolts_t; // maxes at ADC max (1024) * VOLTS_LOW_MULTIPLIER 
typedef uint32_t DisplayPower_t; // In units of  1/128  Watt (e.g. value 128 is 1 watt )
namespace {
    // pin assignments on the PCB
    const int PIN_TXD = 1; // directly control TX pin in sleep mode
    const int PIN_RXD = 0; // ditto
    const int couplerPowerDetectPinIn = 2;
    const int initiateCalibratePinIn = 3;
    const int ALOtripSwitchPinIn = 4;
    const int PowerForwReflSwitchPinIn = 5;
    const int SwrMeterPinOut = 10;
    const int RfMeterPinOut = 11;
    const int PanelLampsPinOut = 9;
    const int Tlc59108PowerEnablePinOut = 8;

    const int ReversePwrAnalogUndividedPinIn = A1;
    const int ForwardPwrAnalogUndividedPinIn = A2;
    const int ReversePwrAnalogLowPinIn = A7;
    const int ForwardPwrAnalogLowPinIn = A0;
    const int HoldTimePotAnalogPinIn = A3;
    const int SP3TinPinIn1 = 7;
    const int SP3TinPinIn2 = 6;

    const int MAXED_ADC = 1022; // this is the highest number we'll believe
    const int SWR_SCALE_PWR = 7;
    const uint16_t SWR_SCALE = 1 << SWR_SCALE_PWR;  // 128
    const long INFINITE_SWR = 100;

    // This is the "display" unit for power: watt times 128
    const int PWR_SCALE_PWR = 7;
    const uint16_t PWR_SCALE = 1 << PWR_SCALE_PWR;  // 128

    const int PWM_MAX_PWR = 8;
    const int PWM_MAX_PLUS1 = 1 << PWM_MAX_PWR;

    const unsigned PWR_BREAKTOHIGH_POINT = 250u * PWR_SCALE;
    const unsigned PWR_BREAKTOLOWLOW_POINT = 20u * PWR_SCALE;

    // RC input is 100K-33nF = RC=3.3msec or 48KHz
    const long TimerLoopIntervalMicroSec = 1500; // sample frequency is 1/1500 usec = 660Hz sampling
    const unsigned MeterUpdateIntervalMsec = 125; // 8Hz
    const unsigned CommUpdateIntervalMsec = 100; // COM port message throttle
    const unsigned long HoldPwrLampsOnMsec = 500; 
    const unsigned HoldHighLedMsec = 400;
    const unsigned long LockoutLengthMsec = 5000;

    const unsigned long FrontPanelLampsOnMsec = 90000; // stay on 90 seconds per RFM documentation
    // DEBUG const unsigned long FrontPanelLampsOnMsec = 10000; 

    const unsigned long SERIAL_BAUD = 38400;

    /* multiply the LOW and UNDIVIDED ADC readings by these two in order to put them in AcquiredVolts_t
    ** The compile time computation here enables run time calculations to scale properly in 32 bit integers (or 64, when coded that way)
    ** and without floating point arithmetic at run time (there IS compile time floating point here.)
    ** 
    ** MULTIPLIER's are chosen so a) the results are in same units and b) an ADC count of 1023 (its max) times the multiplier fits in uint16_t
    ** NominalCouplerResistance is such that dividing into (AcquiredVolts_t * AcquiredVolts_t) gives DisplayPower_t
    ** The  couplers have Schottkey barrier diodes. */
    const double SchottkeyBarrierVolts = .2; 
#ifdef OEM_COUPLER
    // The RFM-003 (3000W) works with these parameters
    const double COUPLER_NOMINAL_WATTS = 1500; // as measured...
    const double COUPLER_NOMINAL_VOLTS = 26; // ...ditto
    const uint16_t VOLTS_LOW_MULTIPLIER = 23;
    const uint16_t VOLTS_UNDIVIDED_MULTIPLER = 3;
#endif
#ifdef W5XD_COUPLER
    /* Inspired by the 2008 Radio Amateur's Handbook, chapter 19, High Power Coupler.
    ** The parameters below should work for that coupler as well as the one documented in this repo.
    ** The differences between the two are (a) the transformers are wound on red powdered iron cores,
    ** but three of them together, and the next diameter bigger. 
    ** b) mechanically, this one is built into a smaller box.
    ** The 40:1 turns ratio is maintained, which is the primary contributer to these parameters */
    const double COUPLER_NOMINAL_WATTS = 100; // as measured...
    const double COUPLER_NOMINAL_VOLTS = 2.2; // as measured PLUS schotkey assumed loss
    const uint16_t VOLTS_LOW_MULTIPLIER = 16; // The "low" is 220K / (100K + 220K) voltage divider = 5/16
    const uint16_t VOLTS_UNDIVIDED_MULTIPLER = 5;
#endif
    const double ADC_BASE_VOLTS = 5;
    const int ADC_RESOLUTION = 1023;
    const int WATTS_TO_DISPLAY_T = 128;
    const double A_T_to_VOLTS = ADC_BASE_VOLTS / ( ADC_RESOLUTION * VOLTS_UNDIVIDED_MULTIPLER * COUPLER_NOMINAL_VOLTS);
    const uint32_t NominalCouplerResistance32 = static_cast<uint32_t>(0.5 + 1.0 / (A_T_to_VOLTS * A_T_to_VOLTS * COUPLER_NOMINAL_WATTS * WATTS_TO_DISPLAY_T));
    static_assert(NominalCouplerResistance32 > 1 && NominalCouplerResistance32 < 64000, "NominalCouplerResistance32");
    const uint16_t NominalCouplerResistance = static_cast<uint16_t>(NominalCouplerResistance32);
    const uint32_t NominalCouplerResistanceMultiplier = 0x20000u; // power of two such that divide is optimized as a shift
    const uint32_t NominalCouplerResistanceRecip32 =
        NominalCouplerResistanceMultiplier / NominalCouplerResistance;
    static_assert(NominalCouplerResistanceRecip32 < 0x10000, "NominalCouplerResistanceRecip32");
    const uint16_t NominalCouplerResistanceRecip = static_cast<uint16_t>(NominalCouplerResistanceRecip32);

    const AcquiredVolts_t SchottkeyBarrier =
        static_cast<AcquiredVolts_t>(VOLTS_UNDIVIDED_MULTIPLER * SchottkeyBarrierVolts * ADC_RESOLUTION / 5.0); // multiply into AcquiredVolts_t

    PowerMeterLeds leds(Tlc59108PowerEnablePinOut);
    int8_t AverageSwitchPinIn = SP3TinPinIn1;
    int8_t PeakSwitchPinIn = SP3TinPinIn2;
    uint16_t PowerMinToDisplay = 10; // in DisplayPower_t units, 1/128 W
    unsigned AdcMinNonzero = 4;
    uint8_t LampsOnPwm=0xff;

    enum EEPROM_ASSIGNMENTS {
        EEPROM_SWR_LOCK, EEPROM_PWR_LOCK, EEPROM_FWD_CALIBRATION, EEPROM_REFL_CALIBRATION, EEPROM_POT_MAX,
        EEPROM_POT_REVERSE = EEPROM_POT_MAX + 2,
        EEPROM_IREF, EEPROM_BRIGHTNESS = EEPROM_IREF+2,
        EEPROM_SP3T_REVERSE, EEPROM_MINPWR,
        EEPROM_ADCMIN = EEPROM_MINPWR + 2,
        EEPROM_LAMPSONPWM = EEPROM_ADCMIN + 2,
        EEPROM_USED = EEPROM_LAMPSONPWM + 1
    };
    uint8_t SwrToMeter(uint16_t swrCoded);
    void PwrToMeter(uint16_t toDisplay); // units of PWR_SCALE
}

namespace movingAverage{
        void clear();
}
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
void loop()
{
#ifdef SUPPORT_WDT
    wdt_reset();
#endif
    previousMicrosec = micros();
    unsigned long now = millis();
    leds.loop(now);
    // throttle to one loop every TimerLoopIntervalMicroSec
    while (Serial.available() > 0)
    {
        static unsigned char numInBuf = 0;
        static char buf[16];
        auto inChar = Serial.read();
        if (islower(inChar))
            inChar = toupper(inChar);
        buf[numInBuf] = inChar;
        if (inChar == '\r' || inChar == '\n')
        {
            buf[numInBuf] = 0;
            if (cmd::strcmp(buf, cmd::P_ON) == 0)
            {   // send serial port AVG power output 
                Comm::OutputToSerial = Comm::AVG_OUTPUT_TO_SERIAL;
                Comm::OutputStartedMsec = now;
            }
            else if (cmd::strcmp(buf, cmd::P_OFF) == 0) // don't send serial port power
                Comm::OutputToSerial = Comm::NO_OUTPUT_TO_SERIAL;
            else if (cmd::strcmp(buf, cmd::P_PEAK) == 0)
            {   // send serial port PEAK power output
                Comm::OutputToSerial = Comm::PEAK_OUTPUT_TO_SERIAL;
                Comm::OutputStartedMsec = now;
            }
            else if (cmd::strcmp(buf, cmd::P_FOREVER) == 0)
            {   // normal operation is that serial port output must be requested every 10 seconds. Keep it on forever
                Comm::forever = !Comm::forever;
                Serial.print(F("P Forever ="));
                Serial.println(Comm::forever ? "1" : "0");
            }
            else if (cmd::strncmp(buf, cmd::POTREVERSE, 11) == 0)
            {   /* If the hold pot is wired backwards, fix in software*/
                EEPROM.write((int)EEPROM_POT_REVERSE, static_cast<uint8_t>(buf[11] == '1' ? 0 : 1));
            }
            else if (cmd::strncmp(buf, cmd::POTMAX, 7) == 0)
            {   /* If the hold pot won't go full scale, EEPROM setting of 0-1023 to specify*/
                uint16_t pmax = atoi(buf+7);
                EEPROM.put((int)EEPROM_POT_MAX, pmax);
            }
            else if (cmd::strncmp(buf, cmd::SP3TUPDOWN, 11) == 0)
            {   /* The front panel SP3T switch can be installed upside down. Fix in software here*/
                bool reverse = buf[11] == '1';
                EEPROM.write((int)EEPROM_SP3T_REVERSE, static_cast<uint8_t>(reverse ? 0 : 1));
                if (reverse)
                {
                    AverageSwitchPinIn = SP3TinPinIn2;
                    PeakSwitchPinIn = SP3TinPinIn1;
                }
                else
                {
                    AverageSwitchPinIn = SP3TinPinIn1;
                    PeakSwitchPinIn = SP3TinPinIn2;
                }
            }
            else if (cmd::strncmp(buf, cmd::PMIN, 5) == 0)
            {
                /* Units of 1/128W, set the minium power to keep the display turned on */
                PowerMinToDisplay = atoi(buf+5);
                EEPROM.put((int)EEPROM_MINPWR, PowerMinToDisplay);
            }
            else if (cmd::strcmp(buf, cmd::POT) == 0)
            {   /* diagnostic hold pot readout*/
                auto potRaw = analogRead(HoldTimePotAnalogPinIn);
                auto potRead = readHoldPot();
                Serial.print(F("Pot raw= "));
                Serial.print(potRaw);
                Serial.print(F(" read= "));
                Serial.println(potRead);
            }
            else if (cmd::strncmp(buf, cmd::IREF, 5) == 0)
            {   /* Set the LED driver chip IREF. (reference current.) 0 is dimmest, 255 is brightest */
                uint8_t iref = atoi(buf + 5);
                EEPROM.put((int)EEPROM_IREF, iref);
                leds.LeftDevice().SetCurrent(iref);
                leds.RightDevice().SetCurrent(iref);
            }
            else if (cmd::strcmp(buf, cmd::LED) == 0)
            {
                /* Turn each of the LEDS on/off*/
                Serial.println("LED test");
#ifdef SUPPORT_WDT
                wdt_disable();
#endif
                leds.test();
#ifdef SUPPORT_WDT
                wdt_enable(WDTO_1S);
#endif
                Serial.println("LED test end");
            }
            else if (cmd::strcmp(buf, cmd::METERS) == 0)
            {   /* Verify the meter labeling. Move meter movements to 
                ** each tick on their printed scales. */
                static const int NUM_TESTS = 6;
                static const uint16_t PowersToDisplay[NUM_TESTS] = 
                {
                    PWR_SCALE * 5,
                    PWR_SCALE * 20,
                    PWR_SCALE * 50,
                    PWR_SCALE * 100,
                    PWR_SCALE * 200,
                    PWR_SCALE * 300
                };
                static const uint16_t SwrsToDisplay[NUM_TESTS] = 
                {
                    static_cast<uint16_t>(1.5f * SWR_SCALE),
                    static_cast<uint16_t>(2.f * SWR_SCALE),
                    static_cast<uint16_t>(3.f * SWR_SCALE),
                    static_cast<uint16_t>(4.f * SWR_SCALE),
                    static_cast<uint16_t>(6.f * SWR_SCALE),
                    static_cast<uint16_t>(10.f * SWR_SCALE),
                };
#ifdef SUPPORT_WDT
                wdt_disable();
#endif
                for (uint8_t i = 0; i < NUM_TESTS; i += 1)
                {
                    for (uint8_t j = 0; j < 10; j++)
                    {
                        PwrToMeter(PowersToDisplay[i]);
                        SwrToMeter(SwrsToDisplay[i]);
                        delay(10);
                    }
                    delay(1000);
                }
#ifdef SUPPORT_WDT
                wdt_enable(WDTO_1S);
#endif
            }
            else if (cmd::strcmp(buf, cmd::ADCX) == 0)
                AdcTest();
            else if (cmd::strncmp(buf, cmd::ADCMIN, 7) == 0)
            {   /* The ADC might not go all the way to zero when there is no signal. Set the lowest nonzero value. 0-255*/
                AdcMinNonzero = atoi(buf + 7);
                EEPROM.put((int)EEPROM_ADCMIN, AdcMinNonzero);
            }
            else if (cmd::strncmp(buf, cmd::BACKLIGHT, 10) == 0)
            {
                uint8_t v = atoi(buf+10);
                Serial.print(F("BACKLIGHT="));
                Serial.println(v);
                LampsOnPwm = v;
                EEPROM.put((int)EEPROM_LAMPSONPWM, LampsOnPwm);
                Backlight(true);
            }
            else if (cmd::strcmp(buf, cmd::TESTWDT) == 0)
            {
#ifdef SUPPORT_WDT
                Serial.println(F("WDT should reboot me shortly!"));
                Serial.flush();
                while (true);
#endif
            }
            else if (cmd::strncmp(buf, cmd::BRI, 4) == 0)
            {   /* 0-255 sets the duty cycle on the LEDS. 255 brightest*/
                uint8_t v = atoi(buf + 4);
                Serial.print(F("BRI="));
                Serial.println(v);
                if (v != 0)
                {
                    leds.SetBrightness(v);
                    EEPROM.write((int)EEPROM_BRIGHTNESS, v);
                }
            }
            else if (cmd::strcmp(buf, cmd::DUMP) == 0)
            {
                leds.LeftDevice().dump();
                leds.RightDevice().dump();
            }
            else if (cmd::strcmp(buf, cmd::RSCALI) == 0)
            {   /* reset FWD/REFL calibration values to default*/
                EEPROM.write((int)EEPROM_FWD_CALIBRATION, 0xff);
                EEPROM.write((int)EEPROM_REFL_CALIBRATION, 0xff);
            }
            numInBuf = 0;
        }
        else numInBuf += 1;
        if (numInBuf >= sizeof(buf) - 1)
            numInBuf = 0;
    }
    sample(); // read FWD/REFL ADCs

    BackPanelPwrSwitchFwd = digitalRead(PowerForwReflSwitchPinIn) == HIGH;
    BackPanelAloSwitchSwr = digitalRead(ALOtripSwitchPinIn) == HIGH;

    auto peakSwitchPinInNow = digitalRead(PeakSwitchPinIn);
    auto averageSwitchPinInNow = digitalRead(AverageSwitchPinIn);
#if 0 // printout when front panel SP3T changes
    static int prevPeak;
    static int prevAverage;
    if ((prevPeak != peakSwitchPinInNow) || (prevAverage != averageSwitchPinInNow))
    {
        if (peakSwitchPinInNow == LOW)
            Serial.println(F("SP3T PEAK"));
        else if (averageSwitchPinInNow == LOW)
            Serial.println(F("SP3T AVERAGE"));
        else
            Serial.println(F("SP3T PEAK HOLD"));
    }
    prevPeak = peakSwitchPinInNow;
    prevAverage = averageSwitchPinInNow;
#endif
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

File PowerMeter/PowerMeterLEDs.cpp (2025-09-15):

#include "PowerMeterLEDs.h"
#define DEBUG 0
static const int AloLockPinOut = 13;
        
PowerMeterLeds::PowerMeterLeds(uint8_t pwrPin, uint8_t Laddr, uint8_t Raddr)
    : m_BankLeft(Laddr), m_BankRight(Raddr)
    , m_PowerEnablePin(pwrPin), m_blinkTime(0), m_BlinkMaskLeft(0), m_BlinkMaskRight(0)
    , m_UpdateLeftMask(~0), m_UpdateRightMask(~0), m_brightness(0x1F)
    , m_BlinkState(true)
{
    memset(m_StateLeft, 0, sizeof(m_StateLeft));
    memset(m_StateRight, 0, sizeof(m_StateRight));
}

void PowerMeterLeds::begin()
{
    pinMode(AloLockPinOut, OUTPUT);
    digitalWrite(AloLockPinOut, LOW);
    pinMode(m_PowerEnablePin, OUTPUT);
    digitalWrite(m_PowerEnablePin, HIGH);
    m_BankLeft.begin();
    m_BankRight.begin();
    m_UpdateLeftMask = ~0;
    m_UpdateRightMask = ~0;
}

static const int BLINK_MSEC = 100;

#ifdef LEDS_ARE_RGB
    static void setRGBYellow(uint8_t brightness, uint8_t &redState, uint8_t &greenState)
    {
            redState = greenState = brightness >> 1;
    }
#endif

void PowerMeterLeds::loop(unsigned long now)
{
    bool blinkChanged = false;
    if (now > (m_blinkTime + BLINK_MSEC))
    {
        m_BlinkState = !m_BlinkState;
        blinkChanged = true;
        m_blinkTime = now;
    }

    uint8_t bright[8];
    uint8_t mask = 1;
    if ((m_UpdateLeftMask != 0) || (m_UpdateRightMask != 0))
    {
        m_BlinkState = true;
        m_blinkTime = now;
    }
    else
    for (uint8_t i = 0; i < 8; i += 1, mask <<= 1)
    {
        if ((m_BlinkMaskLeft & mask) && m_StateLeft[i] != 0)
            m_UpdateLeftMask |= mask;
        if ((m_BlinkMaskRight & mask) && m_StateRight[i] != 0)
            m_UpdateRightMask |= mask;
    }

    if ((m_UpdateLeftMask != 0) || (blinkChanged && m_BlinkMaskLeft != 0))
    {
        mask = 1;
        for (uint8_t i = 0; i < 8; i += 1, mask <<= 1)
        {
            if ((m_BlinkMaskLeft & mask) && !m_BlinkState)
                bright[i] = 0;
            else
                bright[i] = m_StateLeft[i];
        }
        m_BankLeft.UpdatePWM(bright);
        m_UpdateLeftMask = 0;
    }
    if ((m_UpdateRightMask != 0) || (blinkChanged && m_BlinkMaskRight != 0))
    {
        mask = 1;
        for (uint8_t i = 0; i < 8; i += 1, mask <<= 1)
        {
            if ((m_BlinkMaskRight & mask) && !m_BlinkState)
                bright[i] = 0;
            else
                bright[i] = m_StateRight[i];
        }
        m_BankRight.UpdatePWM(bright);
        m_UpdateRightMask = 0;
    }
}

void PowerMeterLeds::BlinkLed(FrontPanel led, bool blink)
{
    uint8_t maskL(0), maskR(0);
    switch (led)
    {
        case FrontPanel::ALO_SENSE:
            maskL |= static_cast<uint8_t>(LedChannel::ALO_SENSE);
            break;
        case FrontPanel::ALO_LOCK:
            maskL |= static_cast<uint8_t>(LedChannel::ALO_LOCK);
            break;
        case FrontPanel::PEAK_SAMPLE:
            maskL |= static_cast<uint8_t>(LedChannel::PEAK_SAMPLE);
            break;

        case FrontPanel::PEAK_HOLD:
            maskR |= static_cast<uint8_t>(LedChannel::PEAK_HOLD);
            break;
        case FrontPanel::RANGE_LOW:
            maskR |= static_cast<uint8_t>(LedChannel::RANGE_LOW);
            break;
        case FrontPanel::RANGE_HIGH:
            maskR |= static_cast<uint8_t>(LedChannel::RANGE_HIGH);
            break;

    }
    if (blink)
    {
        m_BlinkMaskLeft |= maskL;
        m_BlinkMaskRight |= maskR;
    }
    else
    {
        m_BlinkMaskLeft &= ~maskL;
        m_BlinkMaskRight &= ~maskR;
    }
}

void PowerMeterLeds::SetSenseLed(bool amber)
{ 

    auto b1 = m_StateLeft[static_cast<uint8_t>(LedChannel::SENSE_GREEN)];
    auto b2 = m_StateLeft[static_cast<uint8_t>(LedChannel::SENSE_RED)];
    auto b3 = m_StateLeft[static_cast<uint8_t>(LedChannel::SENSE_UNUSED)];
    if (amber)
    {   // Simulate amber as 1.0 Red with 0.75 Green
        m_StateLeft[static_cast<uint8_t>(LedChannel::SENSE_GREEN)] = 3 * (m_brightness >> 2);
        m_StateLeft[static_cast<uint8_t>(LedChannel::SENSE_RED)] = m_brightness;
    }
    else
        m_StateLeft[static_cast<uint8_t>(LedChannel::SENSE_GREEN)] = m_StateLeft[static_cast<uint8_t>(LedChannel::SENSE_RED)] = 0;
    m_StateLeft[static_cast<uint8_t>(LedChannel::SENSE_UNUSED)] = 0;

    if ( b1 != m_StateLeft[static_cast<uint8_t>(LedChannel::SENSE_GREEN)] ||
            b2 != m_StateLeft[static_cast<uint8_t>(LedChannel::SENSE_RED)] ||
            b3 != 0)
        m_UpdateLeftMask |= (1 << static_cast<uint8_t>(LedChannel::SENSE_GREEN))
            | (1 << static_cast<uint8_t>(LedChannel::SENSE_RED))
            | (1 << static_cast<uint8_t>(LedChannel::SENSE_UNUSED));

}

void PowerMeterLeds::SetAloLock(bool red)
{
    auto b1 = m_StateLeft[static_cast<uint8_t>(LedChannel::LOCK_RED)];
    m_StateLeft[static_cast<uint8_t>(LedChannel::LOCK_RED)] = red ? m_brightness : 0;
    digitalWrite(AloLockPinOut, red ? HIGH : LOW);
    if (b1 != m_StateLeft[static_cast<uint8_t>(LedChannel::LOCK_RED)])
        m_UpdateLeftMask |= 1 << static_cast<uint8_t>(LedChannel::LOCK_RED);
}

void PowerMeterLeds::SetSampleLed(bool yellow)
{
#ifdef LEDS_ARE_RGY
    auto b1 = m_StateLeft[static_cast<uint8_t>(LedChannel::SAMPLE_YELLOW)];
    m_StateLeft[static_cast<uint8_t>(LedChannel::SAMPLE_YELLOW)] = yellow ? m_brightness : 0;
    if (b1 != m_StateLeft[static_cast<uint8_t>(LedChannel::SAMPLE_YELLOW)])
        m_UpdateLeftMask |= 1 << static_cast<uint8_t>(LedChannel::SAMPLE_YELLOW);
#endif
#ifdef LEDS_ARE_RGB
    auto b1 = m_StateLeft[static_cast<uint8_t>(LedChannel::SAMPLE_RED)];
    auto b2 = m_StateLeft[static_cast<uint8_t>(LedChannel::SAMPLE_GREEN)];
    auto b3 = m_StateLeft[static_cast<uint8_t>(LedChannel::SAMPLE_BLUE)];
    m_StateLeft[static_cast<uint8_t>(LedChannel::SAMPLE_BLUE)] = 0;
    setRGBYellow(yellow ? m_brightness : 0, 
        m_StateLeft[static_cast<uint8_t>(LedChannel::SAMPLE_RED)], m_StateLeft[static_cast<uint8_t>(LedChannel::SAMPLE_GREEN)]);
    if (b1 != m_StateLeft[static_cast<uint8_t>(LedChannel::SAMPLE_RED)] ||
        b2 != m_StateLeft[static_cast<uint8_t>(LedChannel::SAMPLE_GREEN)] ||
        b3 != 0)
        m_UpdateLeftMask |= (1 << static_cast<uint8_t>(LedChannel::SAMPLE_RED)) 
                | (1 << static_cast<uint8_t>(LedChannel::SAMPLE_GREEN))
                | (1 << static_cast<uint8_t>(LedChannel::SAMPLE_BLUE))
;
#endif
}
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

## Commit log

2016-12-23 use all 256 PWM meter output values
2016-12-25 power up panel lights on calibrate modes
2016-12-26 battery power first draft
2016-12-26 battery power items
2016-12-26 more battery power details
2016-12-26 front panel lamp timeout on calibrate begins on calibrate start
2017-01-30 Show 7805 circuit for PRO
2017-01-30 Power update for PRO
2017-01-30 8V is much better for PRO VIN
2017-01-30 12V DPDT relay to switch battery/external
2017-01-30 relay for power source select
2017-02-02 fix multiplier for 150K input divider
    [PowerMeter.cpp]
2017-02-16 improve sleep current draw from 1000uA down to 750uA
2017-02-20 save a few uA by reconfiguring ADC during sleep
2020-11-28 convert to Arduino ide
2021-01-24 add serial prints of Forward/Reflected
2021-01-25 print locked
2023-11-24 custom pcb
    [1411B.cfg, 1411B.stp, 1411K.cfg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]
2023-11-26 back cover
    [Back Cover.stp, console.cfg]
2023-12-01 schematic png
2023-12-15 gerbers for rev003 of console pcb
2024-01-30 LED lamps now
    [console2.cfg]
2024-02-01 before resize
    [back cover 2.stl, console2.cfg]
2024-02-01 more room
    [Back Panel 2.stl, Base2.stl, back cover 2.stl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]
2024-02-02 bigger tubes
    [console2.cfg]
2024-02-02 back cover stiffen
    [back cover 2.stl, console2.cfg]
2024-02-04 pigtail jig
    [console2.cfg, pigtail jig latch.stl, pigtail jig.cfg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]
2024-02-04 min power limit
2024-02-27 console documentation
    [CliffCon-Spacer.stp, coupler.cfg]
2025-05-21 3D printable console pivot mount mimics OEM dimensions
    [ConsoleBracket.scad, ConsoleBracket.stl]
2025-09-11 Rev 4 of console PCB. Redesign work-alike 3D printed console
    [1411K.cfg, 1411K.stp, 1411Q.cfg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]
2025-09-12 strengthen back panel nut slots
    [console-back panel.stl, console-lid.stl, console.FCStd]
2025-09-13 cosmetic schematic update
    [schematics.sch]
